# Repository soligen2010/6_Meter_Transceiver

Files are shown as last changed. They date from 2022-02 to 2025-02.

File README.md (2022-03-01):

# 6_Meter_Transceiver
A homebrew transceiver for the 6 meter Ham band
 
This project is work in progress.

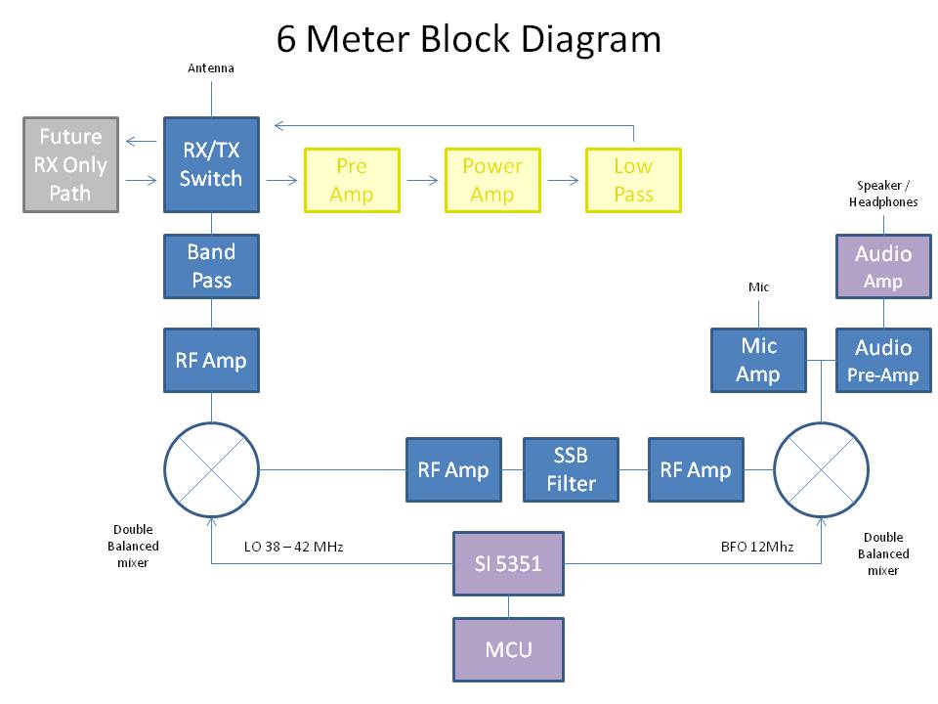
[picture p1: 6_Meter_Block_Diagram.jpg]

 
## 2022-2-27 Status
 
This is my 6 Meter homebrew transceiver, currently work in progress.  It is a single conversion super –heterodyne design.  I constructed each stage independently with SMA connectors.  This is so I can re-make sections as needed, and will allow me in the future to swap sections to experiment with alternate designs.  The VFO and BFO are controlled using a SI5351 with an Arduino micro controller.  I currently have separate SI5351 modules for VFO and BFO because I suspected issues with cross-talk.  These issues may not actually be real, so once I am happy with the performance, I will test again with just one module to see if it is OK.  The Power Amp is still on the to-do list, so output is well under 0 DBm

The Blue boards were designed by me and ordered on-line.  The other boards I etched myself.  Construction is mostly surface mount because I find it easier than drilling all the holes.  SMD components are mostly 805 and 1206 size. Transistors are SOT23.

The Band Pass filter is a 5 coil design made with air-core inductors.

3 bi-directional termination insensitive (TIA) amps are used (blue boards).  Total RX gain is about 44db.  Total TX gain is about 16db.  Each board has its own independent RX/TX switching circuitry (mosfet based) and is fed with +12.5, GND, and RX/TX logic signal from the Arduino (3V logic and up will work)
The Mixer and modulator are both Diode Ring mixers.

The 12 MHz SSB filter is a crystal ladder filter similar to the one used in the uBitx.

The Mic and audio pre-amp (also a blue board) is made on a modified TIA amp board.  I had 10 of these boards made, and the needed circuitry was largely the same, so I modified the board with a rotary tool and jumpers.

The Audio amp is a PAM8403 module and drives a headset.  I did make some modifications to the module so it runs in-spec and to eliminate the power on audio pop.

The challenges I have been having are mostly related to spurs, splatter, carrier suppression and TX audio quality.  I have been gradually tweaking these things to improve operation before I start on a power amp.  My IF is 12 MHZ, and I was using the LSB side of the crystal filter because it is sharper (VFO 62 – 66 MHz) but have recently changed over to the USB side of the filter (VFO 38 – 42 MHz).  This eliminated the spurs I was seeing near the pass band.  I still need to make some adjustments to the crystal filter as it is too broad.

I still have some splatter and audio quality seems low, but I am starting to doubt my test setup.  I see the splatter on the RTL SDR, but I don’t see it on the Tiny SA.  The spatter happens at ~160 KHz intervals.  I am hoping to find someone local with a better spectrum analyzer to help me verify if it is the rig or my SDR dongle/test setup.

The modules to the side of the picture are my rejects/experiments.  The one covered in copper shows how I eventually will shield all the modules.  I 3D printed a cover for the board, then wrapped it with copper tape, soldered to the bottom ground plane.  The one shown is a diode ring modulator.  For some unknown reason the carrier suppression is rather poor.  I had previously made a junk-box modulator that had much better carrier suppression.  I don’t know why it is better than the one I more carefully made for the radio, but until I figure it out, I am using the junk box version.  The junk box modulator uses unmatched schottkey diodes, whereas the “final” one uses a 4 diode SMD package because I wanted them matched – I thought this would be better, but maybe not.

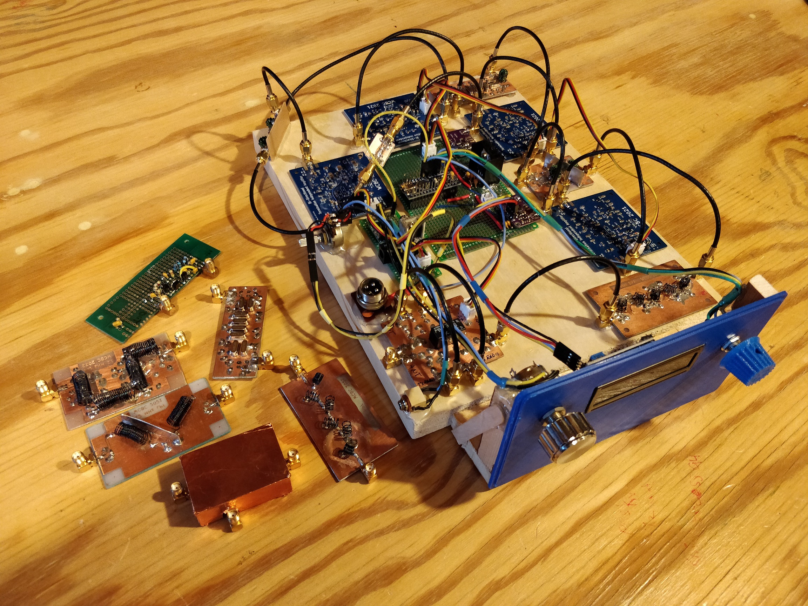
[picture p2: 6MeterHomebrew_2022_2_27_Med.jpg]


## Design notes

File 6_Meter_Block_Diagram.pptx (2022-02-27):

## 6 Meter Block Diagram

Antenna

RX/TX Switch

Band
Pass

FutureRX Only Path

Pre Amp

Power Amp

Low Pass

Speaker / Headphones

Audio Amp

Mic

Mic Amp

RF Amp

Audio Pre-Amp

RF Amp

SSB Filter

RF Amp

Double Balanced mixer

Double Balanced mixer

LO 38 – 42 MHz

SI 5351

BFO 12Mhz

MCU

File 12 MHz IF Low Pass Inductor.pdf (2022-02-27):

Air Cored Inductor Calculator (https://m0ukd.com/calculators/air-cored-inductor-calculator/)

This calculator is useful when making antenna matching units, low pass filters, crystal sets, antenna traps, resonant circuits or anywhere where an air cored single layer inductor is required.

Diameter and length of inductor are entered in millimetres along with the number of turns. Frequency can be entered to find the Q of the inductor at a specific frequency, but is not required. Inductance values are calculated to 3 decimal places and are given in nH, µH, mH and even to 5 decimal places, H! An example of a T-match inductor for 1.8MHz is already inputted, click calculate, or clear fields to enter your own values.

Input coil diameter, length & number of turns

## Calculate

## Clear Fields

Coil Diameter | 7.13 | mm
Coil length | 19 | mm
Number of turns | 19 | t

Frequency
(Not required, but used for calculating Q) | 12 | MHz

Calculated inductance, Q and wire length

Nano H | 817.972 | nH
Micro H | 0.818 | µH
Milli H | 0.001 | mH
Henry | 0.00000 | H
Inductor Q | 156 | Q
Wire Length | 0.43 | m
| 42.56 | cm
425.59 | mm Scroll to Top

This website uses cookies to improve your experience. We'll assume you're ok with this, but you can opt-out

if you wish. Accept Read More (https://m0ukd.com/)

Wire length is calculated by (diameter x π x turns). π is taken to be 3.14159265358979323846264338327950288419716939937510 which is a little over the top I know! As 39 decimal places is sufficient to estimate the circumference of any circle that fits in the observable universe with precision comparable to the radius of a hydrogen atom, the 50 decimal places I have used should be OK for your inductor. Just remember to cut a bit longer for some tails!

This website uses cookies to improve your experience. We'll assume you're ok with this, but you can opt-out

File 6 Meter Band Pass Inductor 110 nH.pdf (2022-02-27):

Air Cored Inductor Calculator (https://m0ukd.com/calculators/air-cored-inductor-calculator/)

This calculator is useful when making antenna matching units, low pass filters, crystal sets, antenna traps,

resonant circuits or anywhere where an air cored single layer inductor is required.

Diameter and length of inductor are entered in millimetres along with the number of turns. Frequency can be

entered to find the Q of the inductor at a specific frequency, but is not required. Inductance values are

calculated to 3 decimal places and are given in nH, µH, mH and even to 5 decimal places, H! An example of

a T-match inductor for 1.8MHz is already inputted, click calculate, or clear fields to enter your own values.

Input coil diameter, length & number of turns

# Calculate

# Clear Fields

Coil Diameter | 4.45 | mm
Coil length | 6.6 | mm
Number of turns | 7 | t

Frequency
(Not required, but used for calculating Q) | 1.850 | MHz

Calculated inductance, Q and wire length
Nano H | 111.413 | nH
Micro H | 0.111 | µH
Milli H | 0.000 | mH
Henry | 0.00000 | H
Inductor Q | 35 | Q
Wire Length | 0.10 | m
| 9.79 | cm
| 97.86 | mm

This website uses cookies to improve your experience. We'll assume you're ok with this, but you can opt-out

## if you wish. Accept Read More (https://m0ukd.com/)

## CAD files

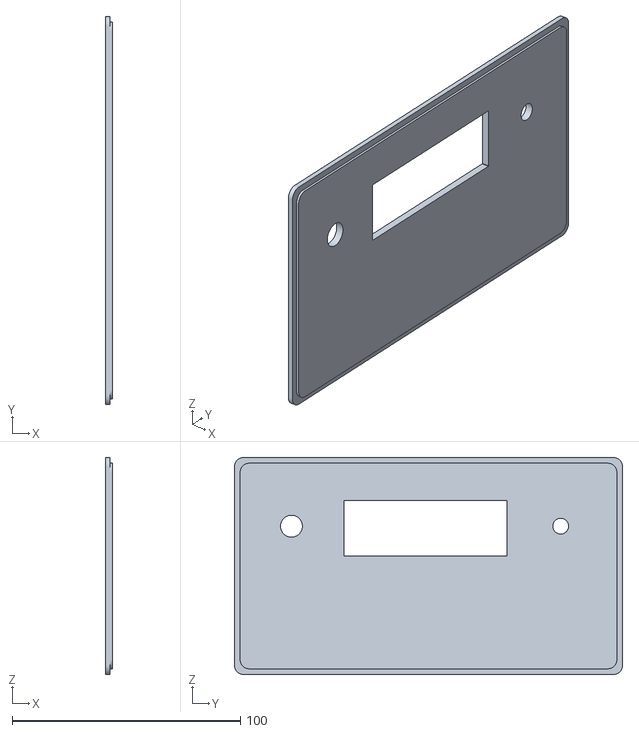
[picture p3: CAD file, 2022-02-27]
6MeterPanel.stl
3.00 x 170.1 x 95.1

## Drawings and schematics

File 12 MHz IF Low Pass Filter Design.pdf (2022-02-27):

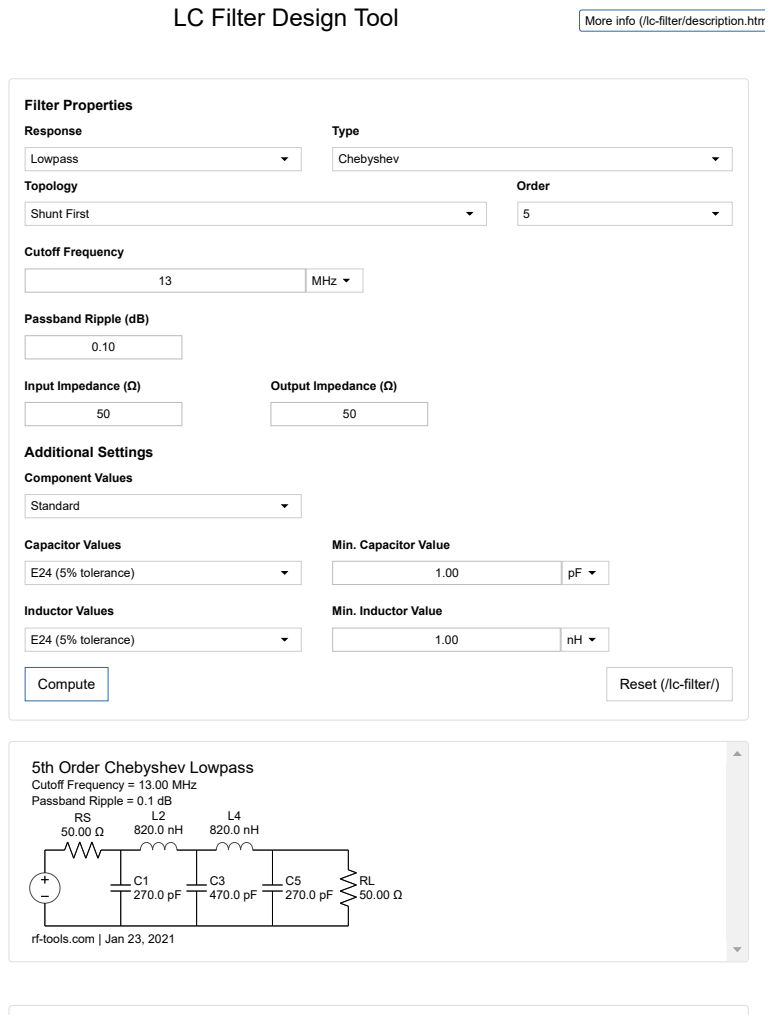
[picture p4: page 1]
LC Filter Design Tool; More info (/lc-filter/description.htm; Filter Properties; Response; Type; Topology; Order; Cutoff Frequency; Input Impedance (Ω); Output Impedance (Ω); Additional Settings; Component Values; Capacitor Values; Min. Capacitor Value; Inductor Values; Min. Inductor Value; Compute; Reset (/lc-filter/); Lowpass; Chebyshev; Shunt First; Standard; E24 (5% tolerance); MHz

Passband Ripple (dB)

5th Order Chebyshev Lowpass
Cutoff Frequency = 13.00 MHz
Passband Ripple = 0.1 dB

rf-tools.com | Jan 23, 2021

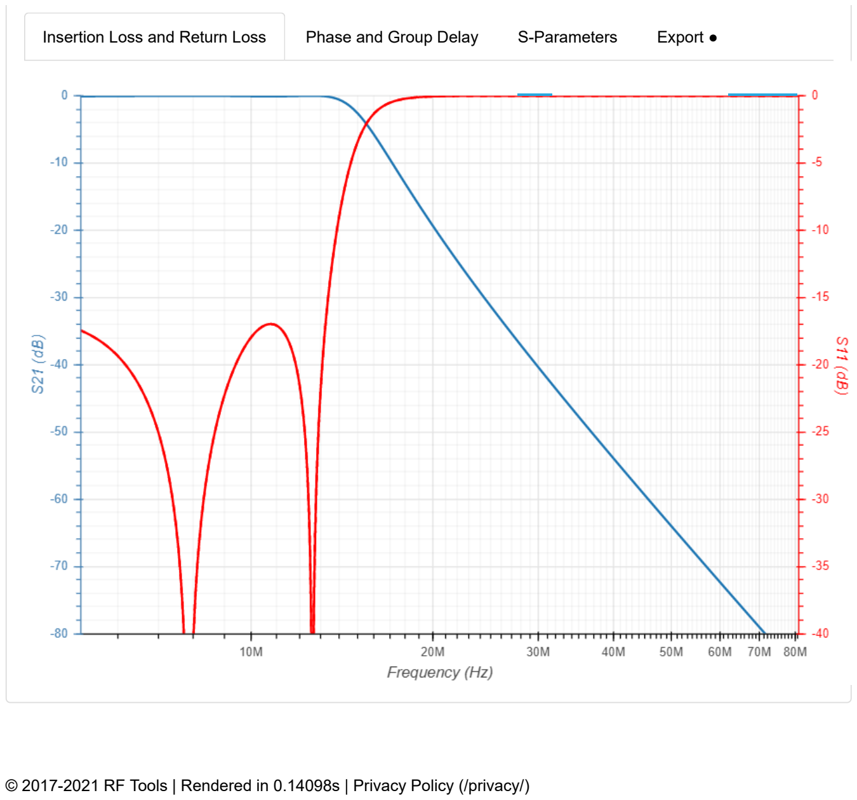
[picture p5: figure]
Insertion Loss and Return Loss; Phase and Group Delay; S-Parameters; Export ●

© 2017-2021 RF Tools | Rendered in 0.14098s | Privacy Policy (/privacy/) (https://rf-tools.com/privacy/)

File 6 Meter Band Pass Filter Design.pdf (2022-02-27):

LC Filter Design Tool | More info (/lc-filter/description.htm (https://rf-tools.com/lc-filter/description.html)

## Filter Properties

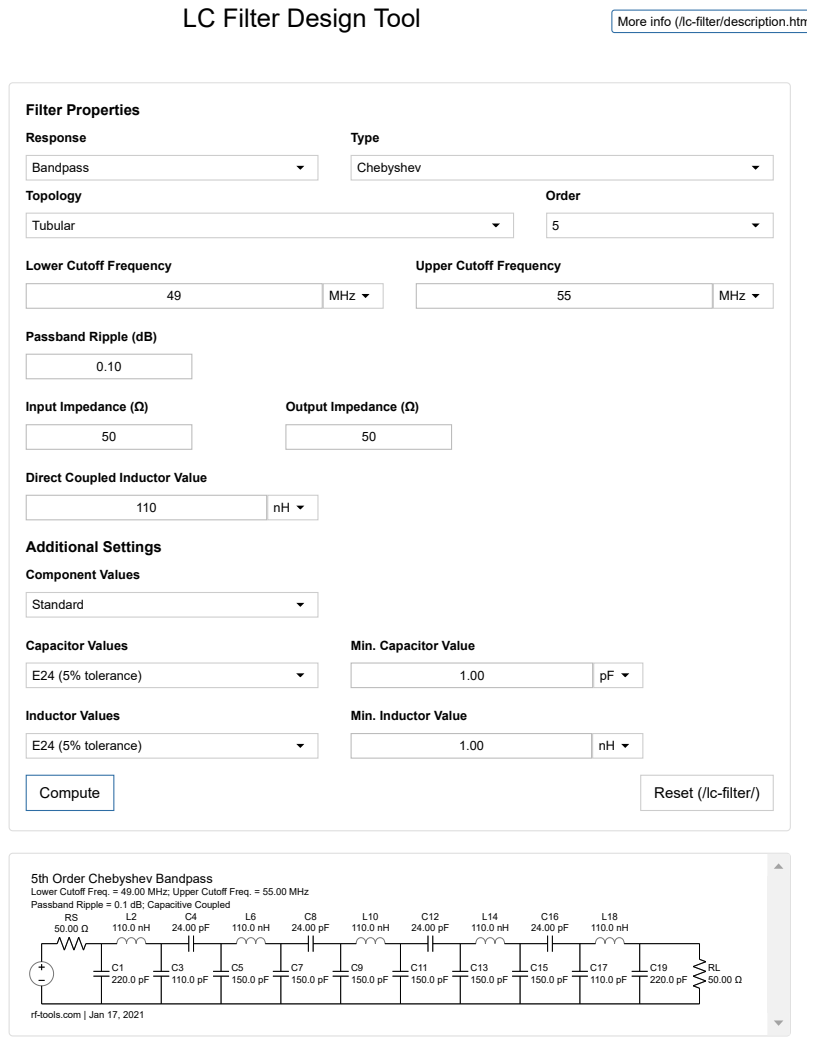
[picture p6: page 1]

Direct Coupled Inductor Value

5th Order Chebyshev Bandpass
Lower Cutoff Freq. = 49.00 MHz; Upper Cutoff Freq. = 55.00 MHz
Passband Ripple = 0.1 dB; Capacitive Coupled

rf-tools.com | Jan 17, 2021

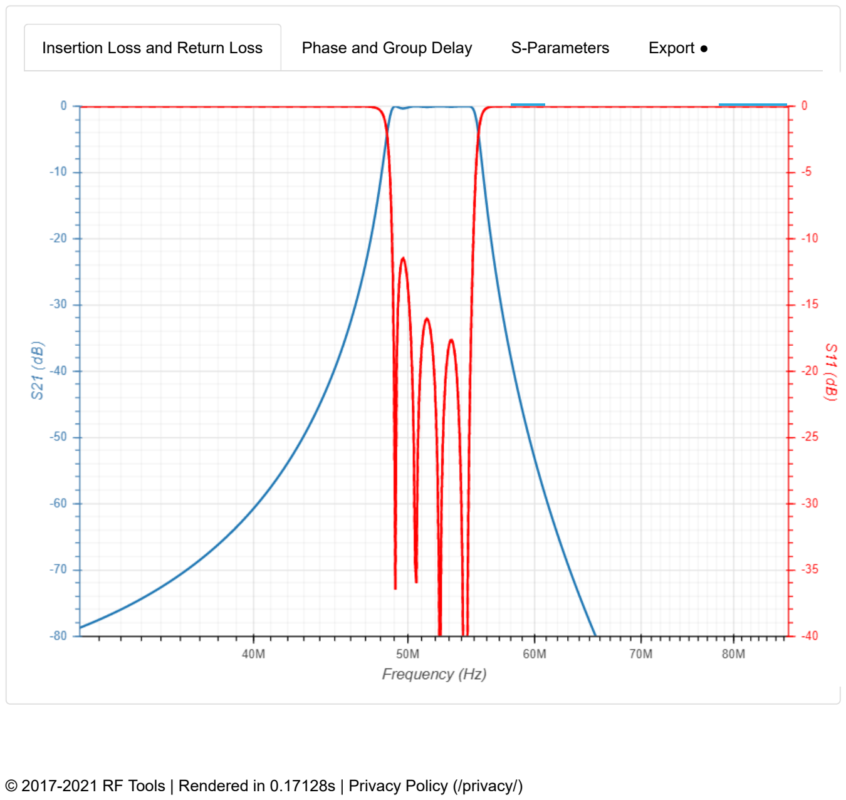
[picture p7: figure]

© 2017-2021 RF Tools | Rendered in 0.17128s | Privacy Policy (/privacy/) (https://rf-tools.com/privacy/)
Insertion Loss and Return Loss | Phase and Group Delay | S-Parameters | Export ●

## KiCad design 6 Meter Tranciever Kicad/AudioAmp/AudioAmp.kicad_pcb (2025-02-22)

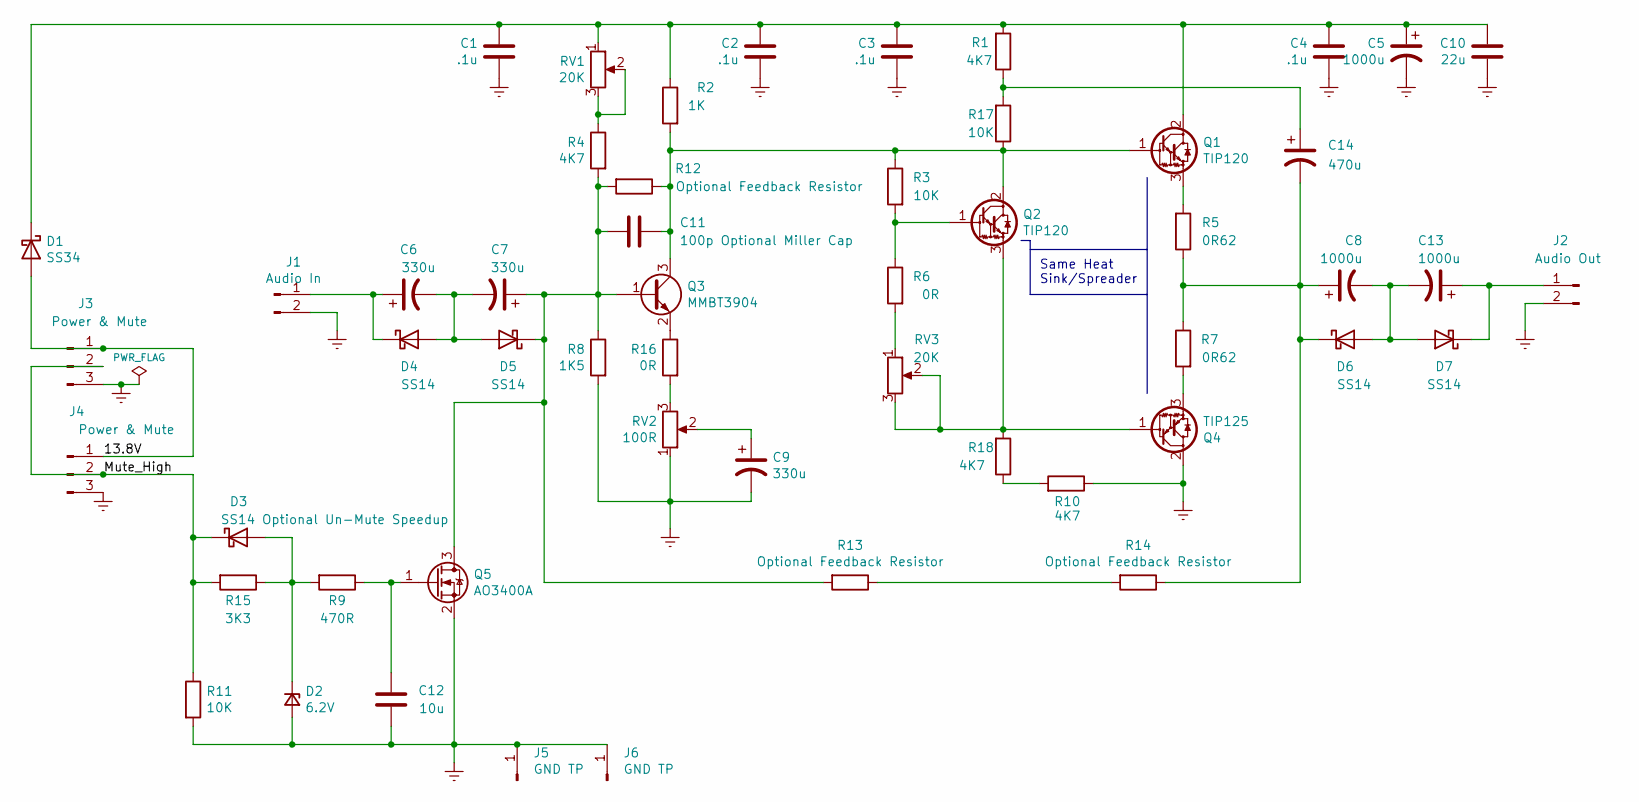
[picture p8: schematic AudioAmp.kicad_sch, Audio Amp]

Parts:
C1, C2, C3, C4: .1u; SMD_Combo_1206_0805
C5: 1000u; CP_Radial_D18.0mm_P7.50mm
C6, C7, C9: 330u; CP_Radial_D13.0mm_P5.00mm
C8, C13: 1000u; CP_Radial_D13.0mm_P5.00mm
C10: 22u; SMD_Combo_1206_0805
C11: 100p Optional Miller Cap; SMD_Combo_1206_0805
C12: 10u; SMD_Combo_1206_0805
C14: 470u; CP_Radial_D13.0mm_P5.00mm
D1: SS34; D_SMA_Handsoldering
D2: 6.2V; D_MiniMELF_Handsoldering
D3: SS14 Optional Un-Mute Speedup; D_SMA_Handsoldering
D4, D5, D6, D7: SS14; D_SMA_Handsoldering
J1: Audio In; Molex_KK-254_AE-6410-02A_1x02_P2.54mm_Vertical
J2: Audio Out; Molex_KK-254_AE-6410-02A_1x02_P2.54mm_Vertical
J3, J4: Power & Mute; FanPinHeader_1x03_P2.54mm_Vertical
J5, J6: GND TP; PinHeader_1x01_P2.54mm_Vertical
Q1, Q2: TIP120; TO-220-3_Vertical
Q3: MMBT3904; SOT-23_Handsoldering
Q4: TIP125; TO-220-3_Vertical
Q5: AO3400A; SOT-23_Handsoldering
R1, R4, R10, R18: 4K7; SMD_Combo_1206_0805
R2: 1K; SMD_Combo_1206_0805
R3, R11, R17: 10K; SMD_Combo_1206_0805
R5, R7: 0R62; R_Axial_DIN0309_L9.0mm_D3.2mm_P12.70mm_Horizontal
R6, R16: 0R; SMD_Combo_1206_0805
R8: 1K5; SMD_Combo_1206_0805
R9: 470R; SMD_Combo_1206_0805
R12, R13, R14: Optional Feedback Resistor; SMD_Combo_1206_0805
R15: 3K3; SMD_Combo_1206_0805
RV1, RV3: 20K; Potentiometer_Piher_PT-6-V_Vertical
RV2: 100R; Potentiometer_Piher_PT-6-V_Vertical

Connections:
/13.8V: D1.2 (A), J3.1, J4.1
/Mute_High: D3.1 (K), J3.2, J4.2, R11.1, R15.2
GNDREF: C1.2, C2.2, C3.2, C4.2, C5.2, C9.2, C10.2, C12.2, D2.2 (A), J1.2, J2.2, J3.3, J4.3, J5.1, J6.1, Q4.2 (C), Q5.2 (S), R8.2, R10.1, R11.2, RV2.1
unnamed: C1.1, C2.1, C3.1, C4.1, C5.1, C10.1, D1.1 (K), Q1.2 (C), R1.2, R2.1, RV1.1
unnamed: C6.1, D4.1 (K), J1.1
unnamed: C6.2, C7.2, D4.2 (A), D5.2 (A)
unnamed: C8.1, C14.2, D6.1 (K), R5.1, R7.1, R14.1
unnamed: C9.1, RV2.2
unnamed: C11.1, Q1.1 (B), Q2.2 (C), Q3.3 (C), R2.2, R3.1, R12.1, R17.1
unnamed: C7.1, C11.2, D5.1 (K), Q3.1 (B), Q5.3 (D), R4.2, R8.1, R12.2, R13.2
unnamed: C12.1, Q5.1 (G), R9.1
unnamed: C13.1, D7.1 (K), J2.1
unnamed: C8.2, C13.2, D6.2 (A), D7.2 (A)
unnamed: C14.1, R1.1, R17.2
unnamed: D2.1 (K), D3.2 (A), R9.2, R15.1
unnamed: Q1.3 (E), R5.2
unnamed: Q2.1 (B), R3.2, R6.1
unnamed: Q2.3 (E), Q4.1 (B), R18.2, RV3.2, RV3.3
unnamed: Q3.2 (E), R16.1
unnamed: Q4.3 (E), R7.2
unnamed: R4.1, RV1.2, RV1.3
unnamed: R6.2, RV3.1
unnamed: R10.2, R18.1
unnamed: R13.1, R14.2
unnamed: R16.2, RV2.3

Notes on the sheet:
Same Heat Sink/Spreader

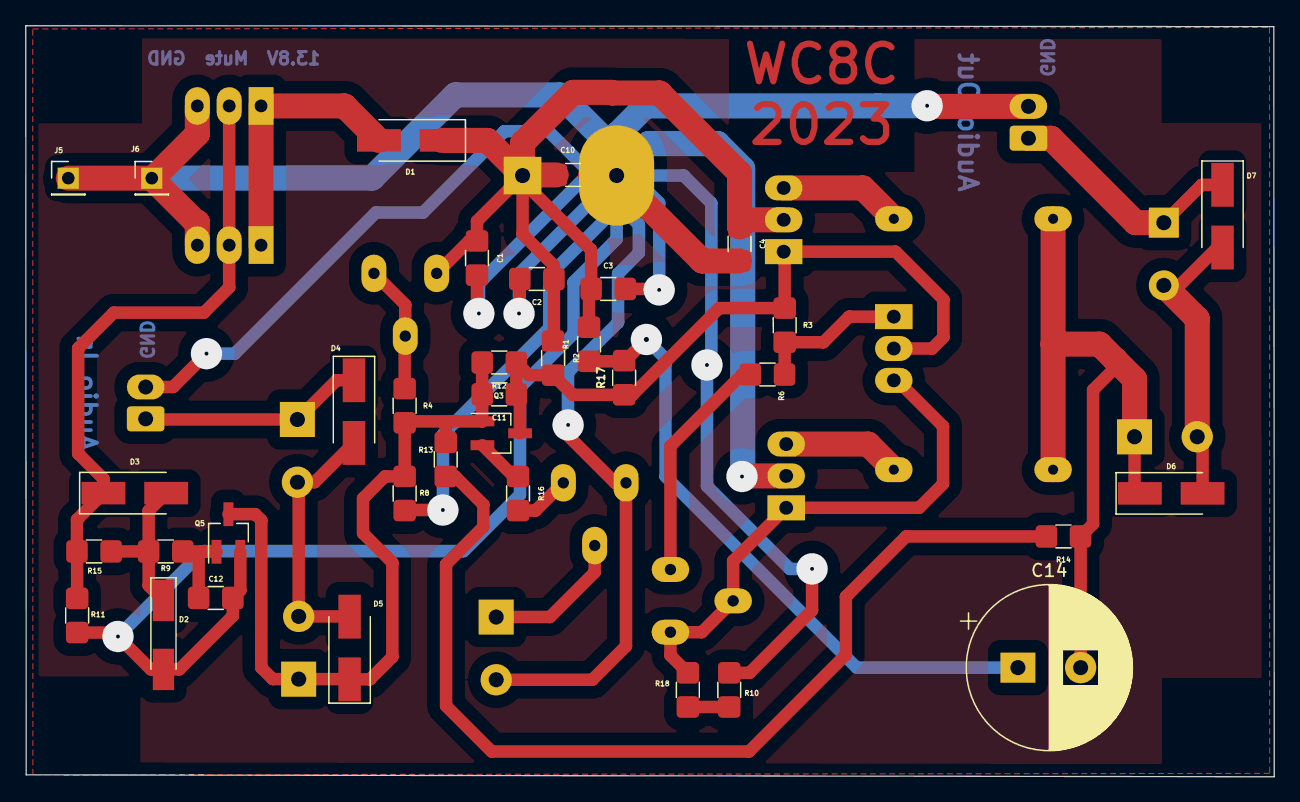
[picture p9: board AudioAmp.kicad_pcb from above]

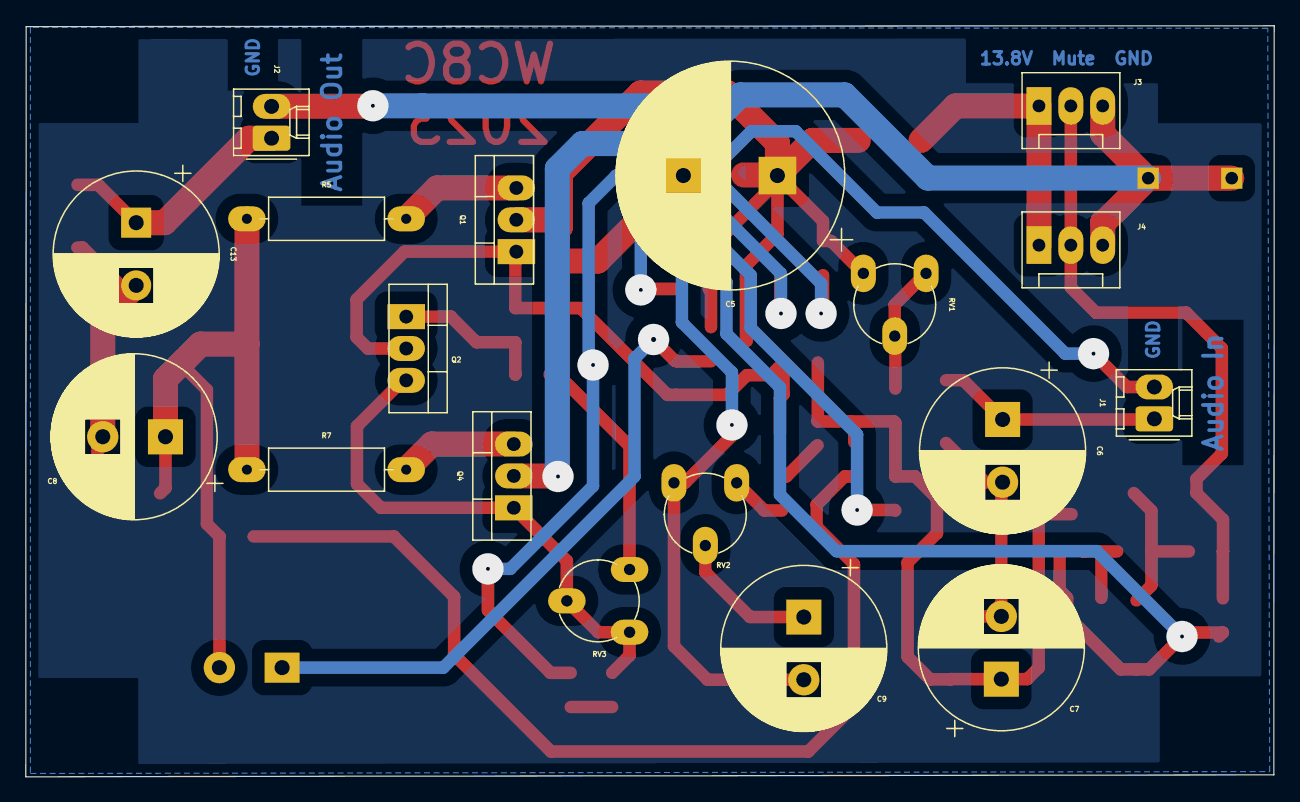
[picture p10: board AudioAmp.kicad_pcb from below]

Board: 2 copper layers, 99.5 x 59.9 mm, 53 parts (18 on the bottom side), 25 nets.

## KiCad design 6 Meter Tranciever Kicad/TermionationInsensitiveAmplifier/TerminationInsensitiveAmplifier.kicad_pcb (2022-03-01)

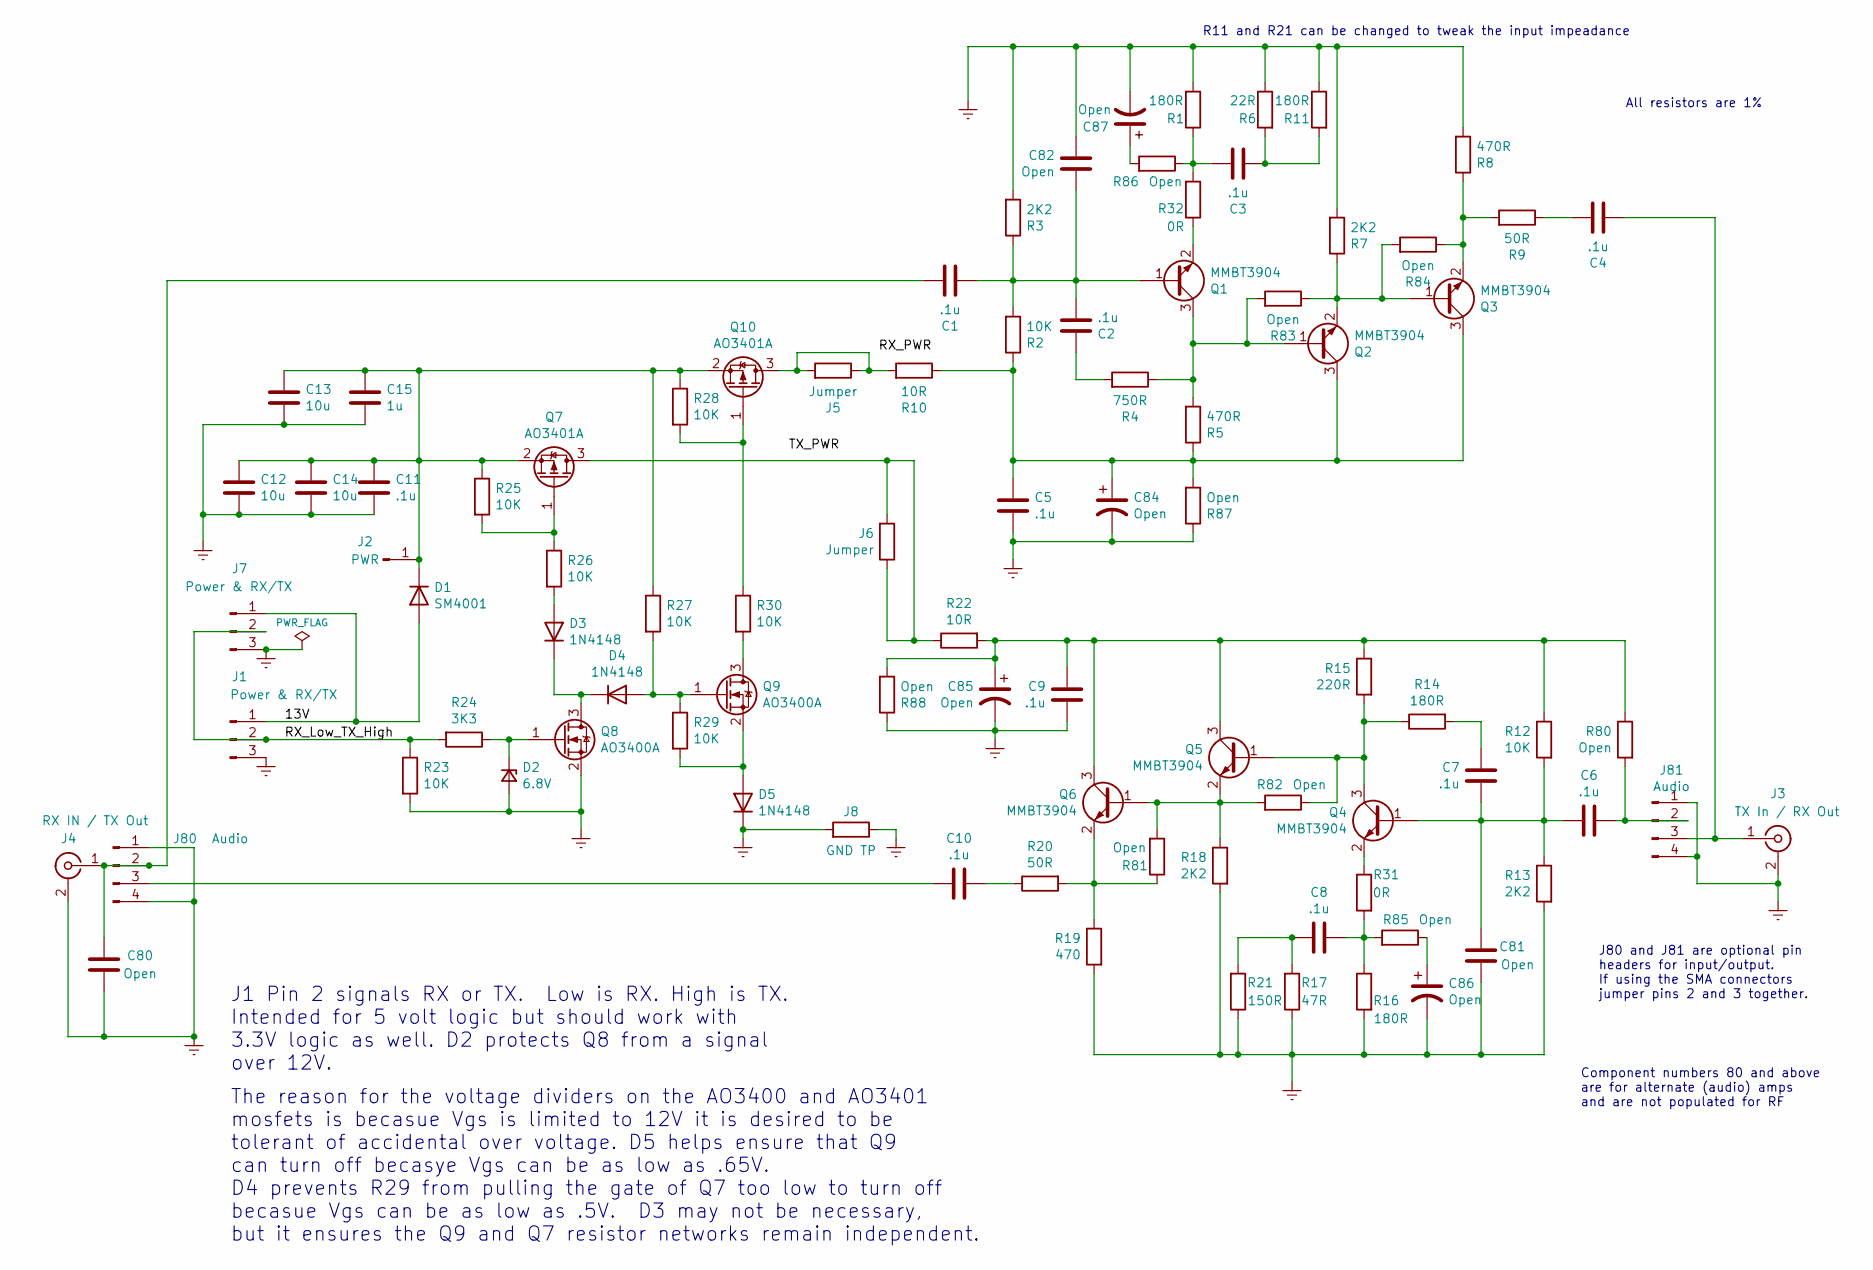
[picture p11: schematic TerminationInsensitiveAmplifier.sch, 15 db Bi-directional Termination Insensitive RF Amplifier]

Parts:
C1, C4, C6, C10: .1u; Cap_0805_1206_6032
C2, C3, C5, C7, C8, C9, C11: .1u; SMD_Combo_1206_0805
C12, C13, C14: 10u; SMD_Combo_1206_0805
C15: 1u; SMD_Combo_1206_0805
C80, C81, C82: Open; SMD_Combo_1206_0805
C84, C85, C86, C87: Open; Cap_0805_1206_6032
D1: SM4001; D_SMA_Handsoldering
D2: 6.8V; D_MiniMELF_Handsoldering
D3, D4, D5: 1N4148; D_SOD-323_HandSoldering
J1, J7: Power & RX/TX; FanPinHeader_1x03_P2.54mm_Vertical
J2: PWR; PinHeader_1x01_P2.54mm_Vertical
J3: TX In / RX Out; SMA_Molex_73251-2120_EdgeMount_Horizontal
J4: RX IN / TX Out; SMA_Molex_73251-2120_EdgeMount_Horizontal
J5, J6: Jumper; R_Axial_DIN0207_L6.3mm_D2.5mm_P7.62mm_Horizontal
J8: GND TP; R_Axial_DIN0207_L6.3mm_D2.5mm_P7.62mm_Horizontal
J80, J81: Audio; PinSocket_1x04_P2.54mm_Vertical
Q1, Q2, Q3, Q4, Q5, Q6: MMBT3904; SOT-23_Handsoldering
Q7, Q10: AO3401A; SOT-23_Handsoldering
Q8, Q9: AO3400A; SOT-23_Handsoldering
R1, R11, R14, R16: 180R; SMD_Combo_1206_0805
R2, R12, R23, R25, R26, R27, R28, R29, R30: 10K; SMD_Combo_1206_0805
R3, R7, R13, R18: 2K2; SMD_Combo_1206_0805
R4: 750R; SMD_Combo_1206_0805
R5, R8: 470R; SMD_Combo_1206_0805
R6: 22R; SMD_Combo_1206_0805
R9, R20: 50R; SMD_Combo_1206_0805
R10, R22: 10R; SMD_Combo_1206_0805
R15: 220R; SMD_Combo_1206_0805
R17: 47R; SMD_Combo_1206_0805
R19: 470; SMD_Combo_1206_0805
R21: 150R; SMD_Combo_1206_0805
R24: 3K3; SMD_Combo_1206_0805
R31, R32: 0R; SMD_Combo_1206_0805
R80, R81, R82, R83, R84, R85, R86, R87, R88: Open; SMD_Combo_1206_0805

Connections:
/13V: D1.2 (A), J1.1, J7.1
/RX_Low_TX_High: J1.2, J7.2, R23.1, R24.2
GNDREF: C5.2, C9.2, C11.2, C12.2, C13.2, C14.2, C15.2, C80.1, C81.2, C82.1, C84.2, C85.2, C86.2, C87.2, D2.2 (A), D5.1 (K), J1.3, J3.2 (Ext), J4.2 (Ext), J7.3, J8.1, J8.2, J80.1, J80.4, J81.1, J81.4, Q8.2 (S), R1.2, R3.2, R6.1, R7.2, R8.2, R11.1, R13.2, R16.2, R17.1, R18.2, R19.2, R21.1, R23.2, R87.1, R88.1; also elsewhere on the board
unnamed: C1.1, C2.2, C82.2, Q1.1 (B), R2.2, R3.1
unnamed: C1.2, C80.2, J4.1 (In), J80.2
unnamed: C2.1, R4.2
unnamed: C3.1, R6.2, R11.2
unnamed: C3.2, R1.1, R32.2, R86.1
unnamed: C4.1, J3.1 (In), J81.3
unnamed: C4.2, R9.1
unnamed 10: C5.1, C84.1, Q2.3 (C), Q3.3 (C), R2.1, R5.1, R10.1, R87.2; also elsewhere on the board
unnamed: C6.1, C7.2, C81.1, Q4.1 (B), R12.2, R13.1
unnamed: C6.2, J81.2, R80.2
unnamed: C7.1, R14.2
unnamed: C8.1, R17.2, R21.2
unnamed: C8.2, R16.1, R31.2, R85.2
unnamed: C10.1, J80.3
unnamed: C10.2, R20.1
unnamed: C11.1, C12.1, C13.1, C14.1, C15.1, D1.1 (K), J2.1, Q7.2 (S), Q10.2 (S), R25.1, R27.1, R28.1
unnamed 19: C9.1, C85.1, Q5.3 (C), Q6.3 (C), R12.1, R15.1, R22.2, R80.1, R88.2; also elsewhere on the board
unnamed 20: C86.1, R85.1; also elsewhere on the board
unnamed 21: C87.1, R86.2; also elsewhere on the board
unnamed: D2.1 (K), Q8.1 (G), R24.1
unnamed: D3.1 (K), D4.1 (K), Q8.3 (D)
unnamed: D3.2 (A), R26.2
unnamed: D4.2 (A), Q9.1 (G), R27.2, R29.1
unnamed: D5.2 (A), Q9.2 (S), R29.2
unnamed: J5.1, J5.2, Q10.3 (D), R10.2
unnamed: J6.1, J6.2, Q7.3 (D), R22.1
unnamed: Q1.2 (E), R32.1
unnamed: Q1.3 (C), Q2.1 (B), R4.1, R5.2, R83.2
unnamed: Q2.2 (E), Q3.1 (B), R7.1, R83.1, R84.2
unnamed: Q3.2 (E), R8.1, R9.2, R84.1
unnamed: Q4.2 (E), R31.1
unnamed: Q4.3 (C), Q5.1 (B), R14.1, R15.2, R82.1
unnamed: Q5.2 (E), Q6.1 (B), R18.1, R81.2, R82.2
unnamed: Q6.2 (E), R19.1, R20.2, R81.1
unnamed: Q7.1 (G), R25.2, R26.1
unnamed: Q9.3 (D), R30.2
unnamed: Q10.1 (G), R28.2, R30.1

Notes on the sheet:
The reason for the voltage dividers on the AO3400 and AO3401 mosfets is becasue Vgs is limited to 12V it is desired to be tolerant of accidental over voltage. D5 helps ensure that Q9 can turn off becasye Vgs can be as low as .65V. D4 prevents R29 from pulling the gate of Q7 too low to turn off beca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
J1 Pin 2 signals RX or TX. Low is RX. High is TX. Intended for 5 volt logic but should work with 3.3V logic as well. D2 protects Q8 from a signal over 12V.
R11 and R21 can be changed to tweak the input impeadance
All resistors are 1%
J80 and J81 are optional pin headers for input/output. If using the SMA connectors jumper pins 2 and 3 together.
Component numbers 80 and above are for alternate (audio) amps and are not populated for RF

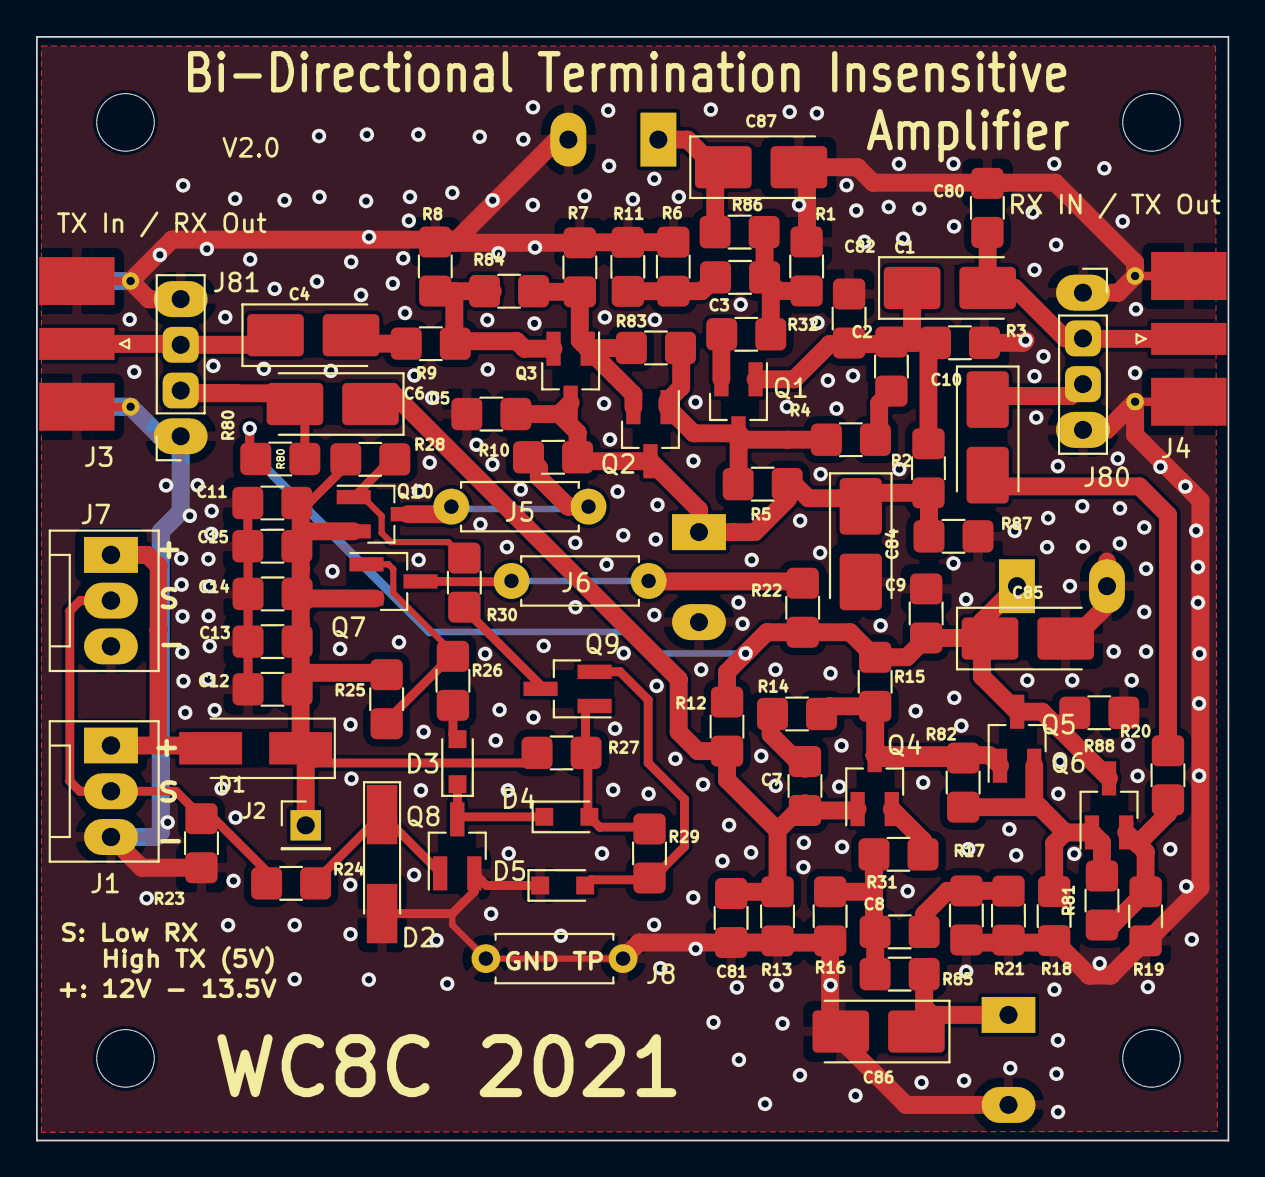
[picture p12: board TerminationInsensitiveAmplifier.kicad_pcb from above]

Board: 2 copper layers, 66.2 x 61.3 mm, 96 parts (0 on the bottom side), 40 nets.

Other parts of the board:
 : 5mm_Pads
 #2,  #3,  #4: 5mm_Pads
 #5,  #6,  #7,  #8: MountingHole_3.2mm_M3

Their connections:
GNDREF: .2, #2.2, #3.2, #4.2; also elsewhere on the board
unnamed 10: .1; also elsewhere on the board
unnamed 19: #2.1; also elsewhere on the board
unnamed 20: #4.1; also elsewhere on the board
unnamed 21: #3.1; also elsewhere on the board

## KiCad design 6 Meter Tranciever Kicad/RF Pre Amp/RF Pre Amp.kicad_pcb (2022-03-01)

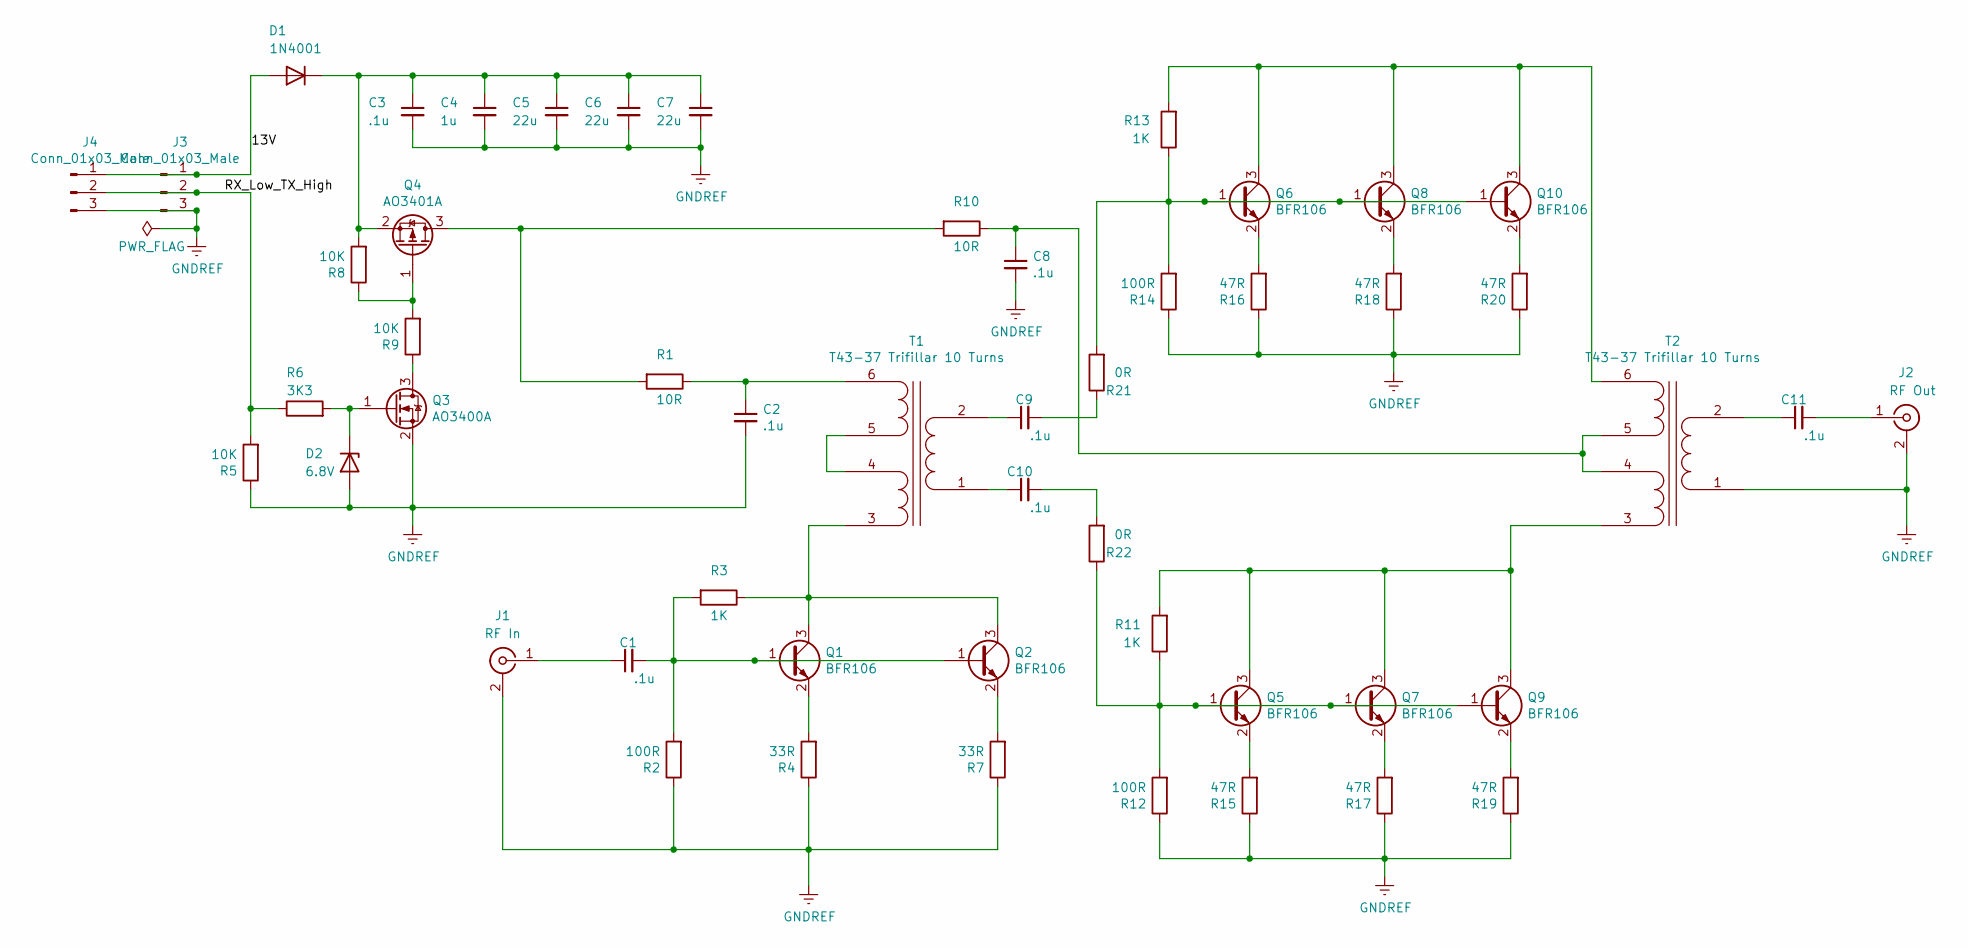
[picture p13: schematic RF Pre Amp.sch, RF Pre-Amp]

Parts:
C1, C2, C3, C8, C9, C10, C11: .1u; SMD_Combo_1206_0805
C4: 1u; SMD_Combo_1206_0805
C5, C6, C7: 22u; SMD_Combo_1206_0805
D1: 1N4001; D_2114_3652Metric_Pad1.85x3.75mm_HandSolder
D2: 6.8V; D_MiniMELF_Handsoldering
J1: RF In; SMA_Molex_73251-2120_EdgeMount_Horizontal
J2: RF Out; SMA_Molex_73251-2120_EdgeMount_Horizontal
J3, J4: Conn_01x03_Male; FanPinHeader_1x03_P2.54mm_Vertical
Q1, Q2, Q5, Q6, Q7, Q8, Q9, Q10: BFR106; SOT-323_SC-70_Handsoldering
Q3: AO3400A; SOT-323_SC-70_Handsoldering
Q4: AO3401A; SOT-323_SC-70_Handsoldering
R1, R10: 10R; SMD_Combo_1206_0805
R2, R12, R14: 100R; SMD_Combo_1206_0805
R3, R11, R13: 1K; SMD_Combo_1206_0805
R4, R7: 33R; SMD_Combo_1206_0805
R5, R8, R9: 10K; SMD_Combo_1206_0805
R6: 3K3; SMD_Combo_1206_0805
R15, R16, R17, R18, R19, R20: 47R; SMD_Combo_1206_0805
R21, R22: 0R; SMD_Combo_1206_0805
T1, T2: T43-37 Trifillar 10 Turns; T37_Trifillar

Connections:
/13V: D1.2 (A), J3.1, J4.1
/RX_Low_TX_High: J3.2, J4.2, R5.2, R6.1
GNDREF: C2.2, C3.2, C4.2, C5.2, C6.2, C7.2, C8.2, D2.2 (A), J1.2 (Ext), J2.2 (Ext), J3.3, J4.3, Q3.2 (S), R2.1, R4.1, R5.1, R7.1, R12.1, R14.1, R15.1, R16.1, R17.1, R18.1, R19.1, R20.1, T2.1 (AA)
unnamed: C1.1, J1.1 (In)
unnamed: C1.2, Q1.1 (B), Q2.1 (B), R2.2, R3.2
unnamed: C2.1, R1.1, T1.6 (SD)
unnamed: C3.1, C4.1, C5.1, C6.1, C7.1, D1.1 (K), Q4.2 (S), R8.2
unnamed: C8.1, R10.1, T2.4 (SB), T2.5 (SC)
unnamed: C9.1, T1.2 (AB)
unnamed: C9.2, R21.1
unnamed: C10.1, T1.1 (AA)
unnamed: C10.2, R22.2
unnamed: C11.1, T2.2 (AB)
unnamed: C11.2, J2.1 (In)
unnamed: D2.1 (K), Q3.1 (G), R6.2
unnamed: Q1.2 (E), R4.2
unnamed: Q1.3 (C), Q2.3 (C), R3.1, T1.3 (SA)
unnamed: Q2.2 (E), R7.2
unnamed: Q3.3 (D), R9.1
unnamed: Q4.1 (G), R8.1, R9.2
unnamed: Q4.3 (D), R1.2, R10.2
unnamed: Q5.1 (B), Q7.1 (B), Q9.1 (B), R11.1, R12.2, R22.1
unnamed: Q5.2 (E), R15.2
unnamed: Q5.3 (C), Q7.3 (C), Q9.3 (C), R11.2, T2.3 (SA)
unnamed: Q6.2 (E), R16.2
unnamed: Q7.2 (E), R17.2
unnamed: Q8.2 (E), R18.2
unnamed: Q9.2 (E), R19.2
unnamed: Q6.1 (B), Q8.1 (B), Q10.1 (B), R13.1, R14.2, R21.2
unnamed: Q10.2 (E), R20.2
unnamed: Q6.3 (C), Q8.3 (C), Q10.3 (C), R13.2, T2.6 (SD)
unnamed: T1.4 (SB), T1.5 (SC)

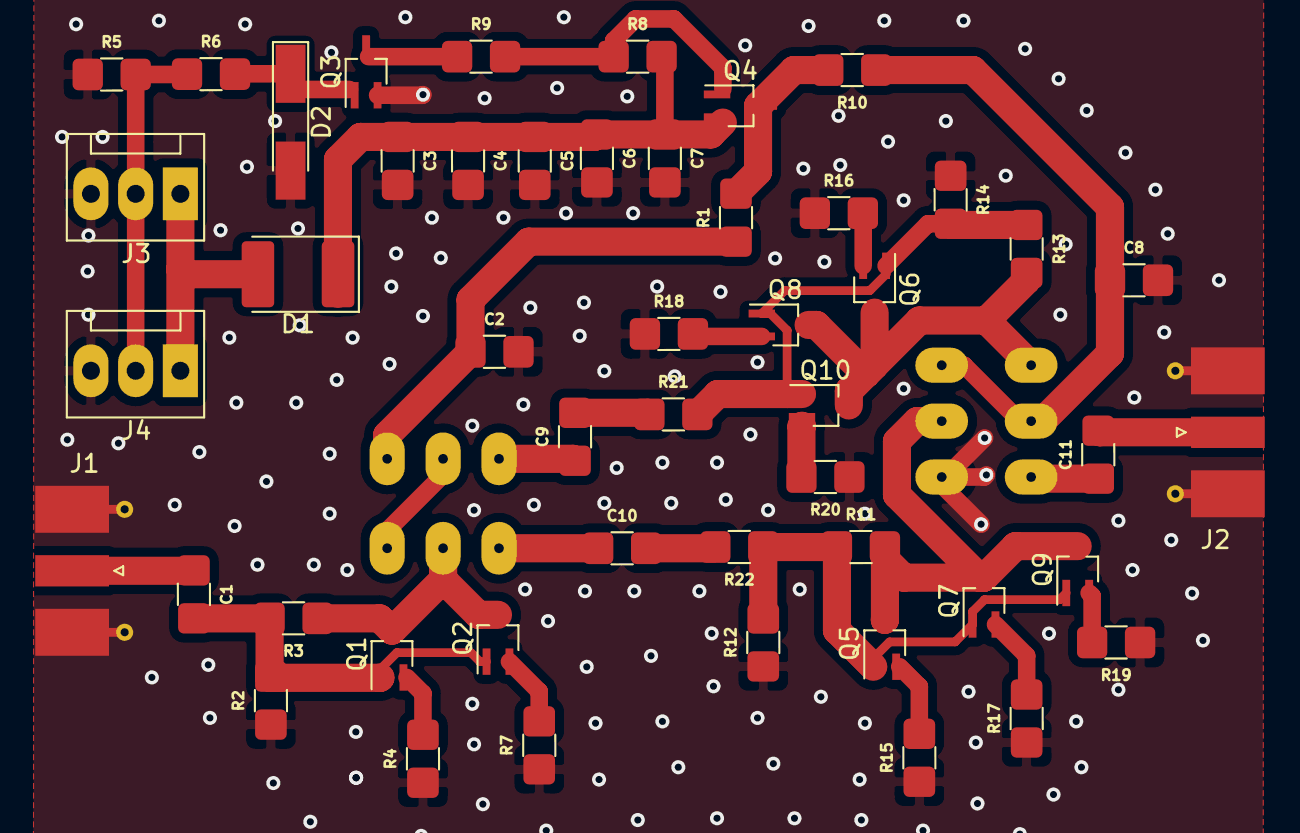
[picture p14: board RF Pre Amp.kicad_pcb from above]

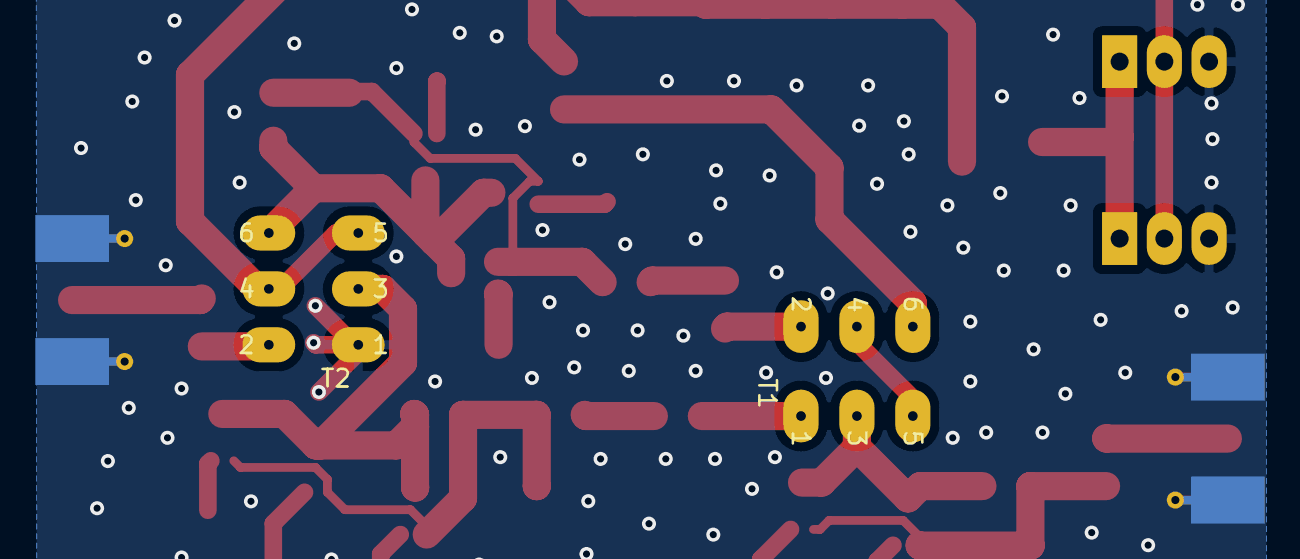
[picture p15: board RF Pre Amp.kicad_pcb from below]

Board: 2 copper layers, 51 parts (2 on the bottom side), 32 nets.

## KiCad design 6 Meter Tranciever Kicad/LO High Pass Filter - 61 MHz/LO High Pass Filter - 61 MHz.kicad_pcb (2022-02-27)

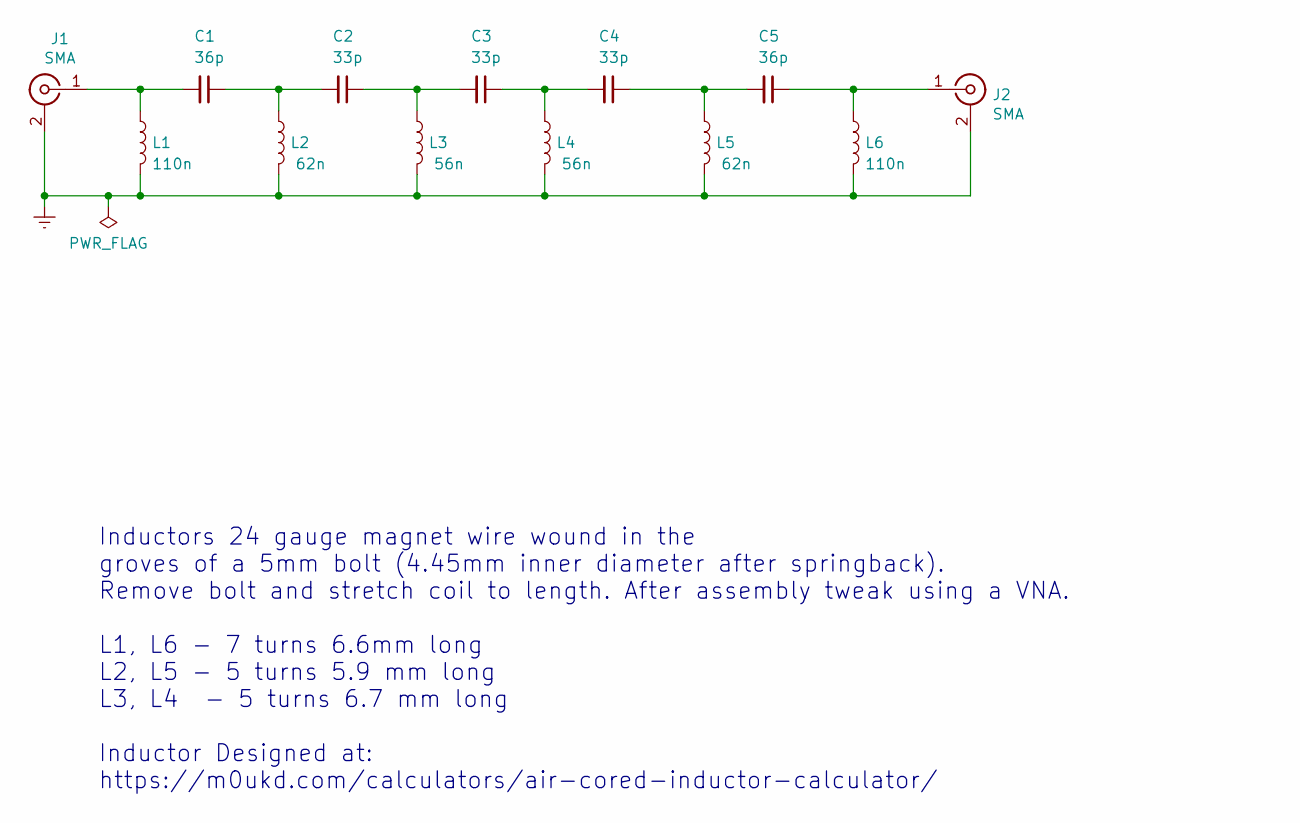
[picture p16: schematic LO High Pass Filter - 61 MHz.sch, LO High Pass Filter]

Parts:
C1, C5: 36p; SMD_Combo_1206_0805
C2, C3, C4: 33p; SMD_Combo_1206_0805
J1, J2: SMA; SMA_Molex_73251-2120_EdgeMount_Horizontal
L1, L6: 110n; Air_Inductor_6.75mm
L2, L5: 62n; Air_Inductor_6.75mm
L3, L4: 56n; Air_Inductor_6mm

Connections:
GNDREF: J1.2 (Ext), J2.2 (Ext), L1.2, L2.2, L3.2, L4.2, L5.2, L6.2
unnamed: C1.1, C2.2, L2.1
unnamed: C1.2, J1.1 (In), L1.1
unnamed: C2.1, C3.2, L3.1
unnamed: C3.1, C4.2, L4.1
unnamed: C4.1, C5.2, L5.1
unnamed: C5.1, J2.1 (In), L6.1

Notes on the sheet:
Inductors 24 gauge magnet wire wound in the groves of a 5mm bolt (4.45mm inner diameter after springback). Remove bolt and stretch coil to length. After assembly tweak using a VNA. L1, L6 - 7 turns 6.6mm long L2, L5 - 5 turns 5.9 mm long L3, L4 - 5 turns 6.7 mm long Inductor Designed at: https://m0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

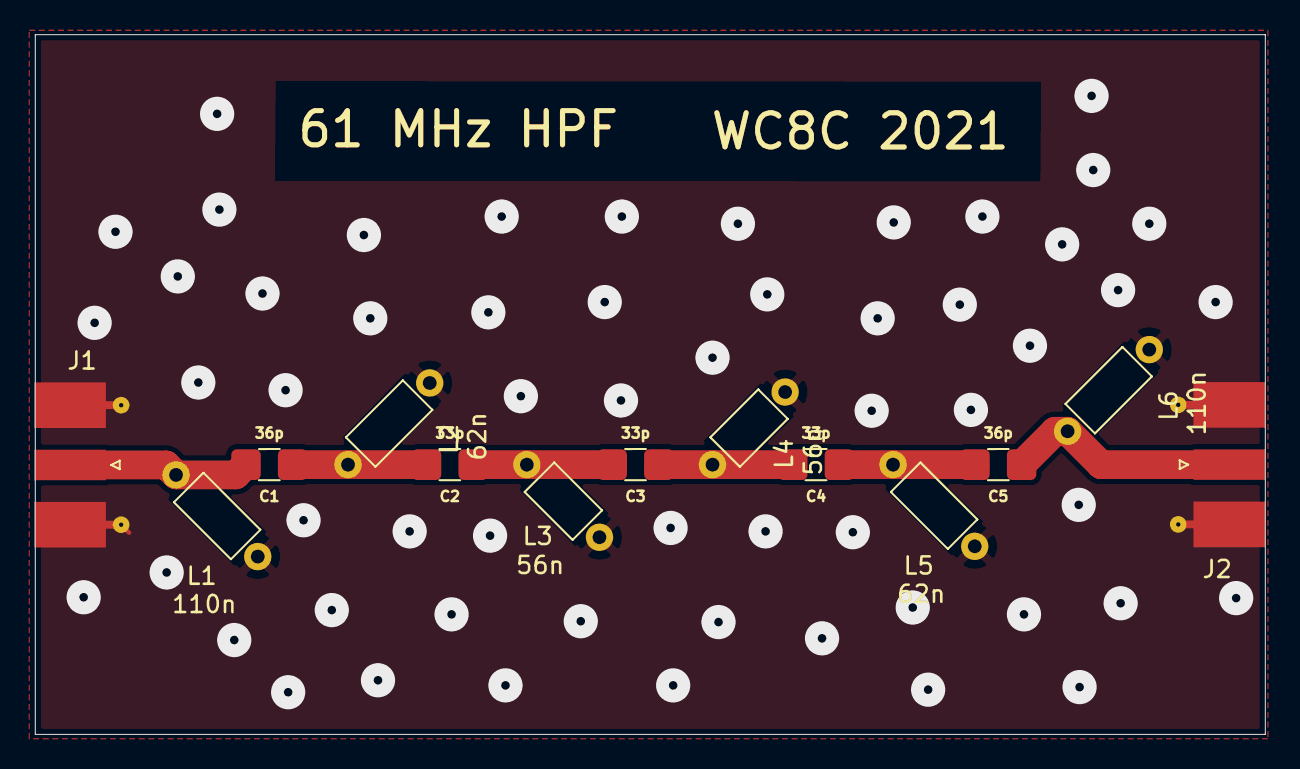
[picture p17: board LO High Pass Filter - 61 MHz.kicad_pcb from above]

Board: 2 copper layers, 71.9 x 40.9 mm, 13 parts (0 on the bottom side), 7 nets.

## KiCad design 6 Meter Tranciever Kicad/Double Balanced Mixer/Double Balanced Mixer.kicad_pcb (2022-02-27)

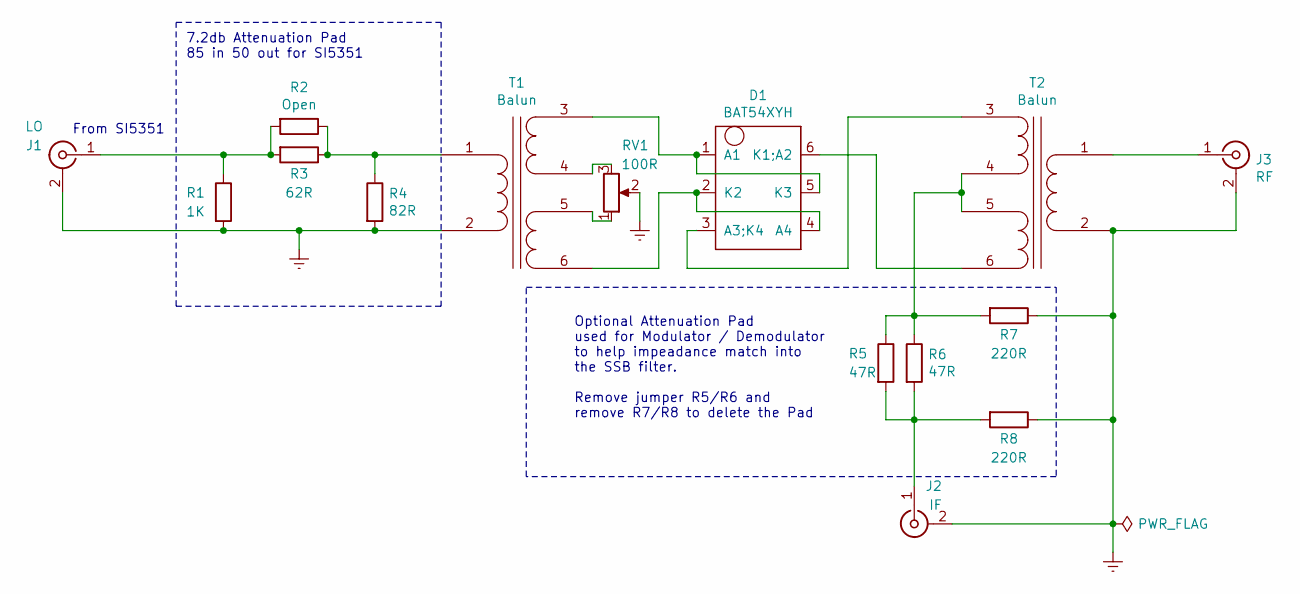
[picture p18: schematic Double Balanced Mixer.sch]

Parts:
D1: BAT54XYH; SOT-363_SC-70-6_Handsoldering
J1: LO; SMA_Molex_73251-2120_EdgeMount_Horizontal
J2: IF; SMA_Molex_73251-2120_EdgeMount_Horizontal
J3: RF; SMA_Molex_73251-2120_EdgeMount_Horizontal
R1: 1K; SMD_Combo_1206_0805
R2: Open; SMD_Combo_1206_0805
R3: 62R; SMD_Combo_1206_0805
R4: 82R; SMD_Combo_1206_0805
R5, R6: 47R; SMD_Combo_1206_0805
R7, R8: 220R; SMD_Combo_1206_0805
RV1: 100R; Potentiometer_Piher_PT-6-V_Vertical
T1, T2: Balun; T37_Trifillar

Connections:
GNDREF: J1.2 (Ext), J2.2 (Ext), J3.2 (Ext), R1.2, R4.2, R7.1, R8.1, RV1.2, T1.2 (AB), T2.2 (AB)
unnamed: D1.1 (A1), D1.5 (K3), T1.3 (SA)
unnamed: D1.2 (K2), D1.4 (A4), T1.6 (SD)
unnamed: D1.3 (A3;K4), T2.3 (SA)
unnamed: D1.6 (K1;A2), T2.6 (SD)
unnamed: J1.1 (In), R1.1, R2.2, R3.2
unnamed: J2.1 (In), R5.2, R6.2, R8.2
unnamed: J3.1 (In), T2.1 (AA)
unnamed: R2.1, R3.1, R4.1, T1.1 (AA)
unnamed: R5.1, R6.1, R7.2, T2.4 (SB), T2.5 (SC)
unnamed: RV1.1, T1.5 (SC)
unnamed: RV1.3, T1.4 (SB)

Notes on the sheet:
7.2db Attenuation Pad 85 in 50 out for SI5351
From SI5351
Optional Attenuation Pad used for Modulator / Demodulator to help impeadance match into the SSB filter. Remove jumper R5/R6 and remove R7/R8 to delete the Pad

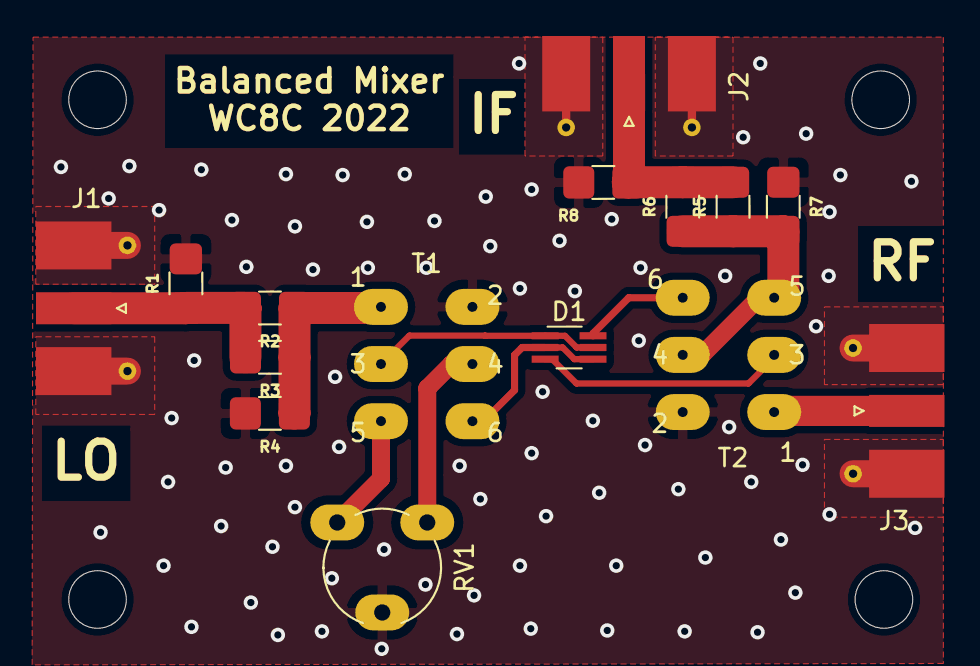
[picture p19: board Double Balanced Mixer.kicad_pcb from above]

Board: 2 copper layers, 19 parts (0 on the bottom side), 12 nets.

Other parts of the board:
 : MountingHole_3.2mm_M3
 #2,  #3,  #4: MountingHole_3.2mm_M3

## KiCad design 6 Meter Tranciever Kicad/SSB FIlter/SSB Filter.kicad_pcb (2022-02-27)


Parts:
C1, C2, C3, C4, C5, C6: 68p; SMD_Combo_1206_0805
J1, J2: Conn_Coaxial; SMA_Molex_73251-2120_EdgeMount_Horizontal
T1, T2: Impeadance Transformer; T37_AutoTransformerParallel
Y1, Y2, Y3, Y4, Y5, Y6, Y7, Y8, Y9: 12MHz; Crystal_HC49-4H_Vertical

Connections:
GNDREF: C1.2, C2.2, C3.2, C4.2, C5.2, C6.2, J1.2 (Ext), J2.2 (Ext), T1.4 (SD), T2.4 (SD)
unnamed: C1.1, Y1.2, Y2.2, Y3.1
unnamed: C2.1, Y3.2, Y4.1
unnamed: C3.1, Y4.2, Y5.1
unnamed: C4.1, Y5.2, Y6.1
unnamed: C5.1, Y6.2, Y7.1
unnamed: C6.1, Y7.2, Y8.1, Y9.1
unnamed: J1.1 (In), T1.2 (SB), T1.3 (SC)
unnamed: J2.1 (In), T2.2 (SB), T2.3 (SC)
unnamed: T1.1 (SA), Y1.1, Y2.1
unnamed: T2.1 (SA), Y8.2, Y9.2

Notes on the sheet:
Capacitors are all 1%. Determined experimentally. Each board / set of crystals may vary.
T1 and T4 startes as a 4:1 impeadance transformer 11 turns eaither side of center FT43-37. Later added 1 extra turn to ground leg to imptove impeadance match.

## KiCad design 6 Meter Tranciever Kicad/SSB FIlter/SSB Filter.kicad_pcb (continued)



Board: 2 copper layers, 76.2 x 27.9 mm, 21 parts (9 on the bottom side), 11 nets.

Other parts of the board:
 : MountingHole_3.2mm_M3
 #2: MountingHole_3.2mm_M3

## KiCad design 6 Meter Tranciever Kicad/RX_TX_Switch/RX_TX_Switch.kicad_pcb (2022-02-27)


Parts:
C1: 10u; SMD_Combo_1206_0805
C2: .1u; SMD_Combo_1206_0805
D1, D2: 1N4148; D_SOD-323_HandSoldering
D3: 6.8V; D_MiniMELF_Handsoldering
D4, D5: SM4004; D_SMA_Handsoldering
J1: Radio; SMA_Molex_73251-2120_EdgeMount_Horizontal
J2: RX from Ant; SMA_Molex_73251-2120_EdgeMount_Horizontal
J3: RX to Radio; SMA_Molex_73251-2120_EdgeMount_Horizontal
J4: TX to Ant; SMA_Molex_73251-2120_EdgeMount_Horizontal
J5: TX from Radio; SMA_Molex_73251-2120_EdgeMount_Horizontal
J6: Antenna; SMA_Molex_73251-2120_EdgeMount_Horizontal
J7: Power & RX/TX; FanPinHeader_1x03_P2.54mm_Vertical
K1: FINDER-44.52; Relay_DPDT_Omron_G5V-2
Q1: AO3400; SOT-23_Handsoldering
R1: 10K; SMD_Combo_1206_0805
R2: 3K3; SMD_Combo_1206_0805
R3: 100K; SMD_Combo_1206_0805

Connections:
/13V: D4.2 (A), J7.1
GNDREF: C1.2, C2.2, D1.1 (K), D2.2 (A), D3.2 (A), J1.2 (Ext), J2.2 (Ext), J3.2 (Ext), J4.2 (Ext), J5.2 (Ext), J6.2 (Ext), J7.3, Q1.2 (S), R1.2, R3.2
unnamed: C1.1, C2.1, D4.1 (K), D5.1 (K), K1.1, R3.1
unnamed: D1.2 (A), D2.1 (K), J2.1 (In), K1.11
unnamed: D3.1 (K), Q1.1 (G), R2.1
unnamed: D5.2 (A), K1.16, Q1.3 (D)
unnamed: J1.1 (In), K1.4
unnamed: J3.1 (In), K1.6
unnamed: J4.1 (In), K1.9
unnamed: J5.1 (In), K1.8
unnamed: J6.1 (In), K1.13
unnamed: J7.2, R1.1, R2.2


Board: 2 copper layers, 53.2 x 58.2 mm, 23 parts (0 on the bottom side), 12 nets.

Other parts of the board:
 : MountingHole_3.2mm_M3
 #2,  #3,  #4: MountingHole_3.2mm_M3

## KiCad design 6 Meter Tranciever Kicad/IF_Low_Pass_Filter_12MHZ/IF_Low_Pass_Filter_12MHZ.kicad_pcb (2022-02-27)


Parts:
C1, C3: 270p; SMD_Combo_1206_0805
C2: 470p; SMD_Combo_1206_0805
J1, J2: SMA; SMA_Molex_73251-2120_EdgeMount_Horizontal
L1, L2: 820n; C_Axial_L12.0mm_D6.5mm_P20.00mm_Horizontal

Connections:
GNDREF: C1.2, C2.2, C3.2, J1.2 (Ext), J2.2 (Ext)
unnamed: C1.1, J1.1 (In), L1.1
unnamed: C2.1, L1.2, L2.1
unnamed: C3.1, J2.1 (In), L2.2

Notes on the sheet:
Inductors are 19 turns 19mm long 24 gauge magnet wire wound tightly on a 1/4" rod (7.13 mm inner diameter after springback). Remove rod and stretch coil to 19mm. Inductor Designed at: https://m0ukd.com/calculators/air-cored-inductor-calculator/


Board: 2 copper layers, 7 parts (0 on the bottom side), 4 nets.

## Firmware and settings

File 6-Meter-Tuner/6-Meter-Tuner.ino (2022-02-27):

/*
 * Requires NewLiquidCrystal library
 * Requires TimerOne library
 * 
 * 
 * 
 */

#include "si5351mcu.h"
#include "BtnEncoder.h"
#include <LiquidCrystal_I2C.h>
#include <TimerOne.h>

// Un-Allocated Pins: 9, A2, A3

#define ENCODER_PINA               2
#define ENCODER_PINB               3
#define ENCODER_BTN                4
#define ENCODER_STEPS_PER_NOTCH    4   // Change this depending on which encoder is used

#define PTT_BTN                    5
#define CW_KEYER_PIN               A6  // CW Keyer
#define AUDIO_MUTE_PIN             6
#define TX_RX_PIN                  12
#define CW_TONE_PIN                10
#define CW_KEY                     A0  // Turns on CW carrier
#define ANALOG_SMETER              A7
#define ENGAGE_AMP_PIN             11
#define LED_PIN                    13

#define SOFT_I2C_SDA               7
#define SOFT_I2C_SCL               8

#define HARD_I2C_SDA               A4
#define HARD_I2C_SCL               A5

ClickEncoder encoder = ClickEncoder(ENCODER_PINA,ENCODER_PINB,ENCODER_BTN,ENCODER_STEPS_PER_NOTCH);
DigitalButton ptt = DigitalButton(PTT_BTN, false);

//#define LCD_I2C_ADDR     0x3F
#define LCD_I2C_ADDR     0x27
#define I2C_EN_PIN              2
#define I2C_RW_PIN              1
#define I2C_RS_PIN              0
#define I2C_D4_PIN              4
#define I2C_D5_PIN              5
#define I2C_D6_PIN              6
#define I2C_D7_PIN              7
#define I2C_BL_PIN              3   //Back light
#define I2C_BACKLIGHT_POLARITY  POSITIVE

LiquidCrystal_I2C lcd(LCD_I2C_ADDR,   // Set the LCD I2C address
                      I2C_EN_PIN,
                      I2C_RW_PIN,
                      I2C_RS_PIN,
                      I2C_D4_PIN,
                      I2C_D5_PIN,
                      I2C_D6_PIN,
                      I2C_D7_PIN,
                      I2C_BL_PIN,
                      I2C_BACKLIGHT_POLARITY);  

#define USB_FILTER                 -1
#define LSB_FILTER                 1
#define CRYSTAL_FILTER_SIDE        USB_FILTER 
#define CRYSTAL_FILTER_WIDTH       3500 
#define CRYSTAL_FILTER_UPPER_EDGE  12000600 

// Frequencies are in Hz
#define SI5351_CLOCK_FREQ  25000000
#define TUNE_START_FREQ    50000000 
#define TUNE_END_FREQ      54000000
#define BFO_BASE_FREQ      (CRYSTAL_FILTER_UPPER_EDGE - (CRYSTAL_FILTER_SIDE == 1 ? 0 : CRYSTAL_FILTER_WIDTH))
#define CW_TONE_FREQ       700
#define START_FREQ         50100000

#define VFO_CHANNEL        2
#define BFO_CHANNEL        0
#define VFO_CORRECTION     -340
#define BFO_CORRECTION     195

Si5351mcu vfoGenerator;
Si5351mcu2 bfoGenerator;

int32_t frequencyIncrement = 1000;
int32_t tuneFrequency = START_FREQ;

int32_t bfoAdjustment = 0;

void timerIsr() {
  encoder.service();
  ptt.service();
}
void setup() {
  digitalWrite(AUDIO_MUTE_PIN, HIGH);    // set to mute
  pinMode(AUDIO_MUTE_PIN, OUTPUT); // set to mute
  
  digitalWrite(LED_PIN, LOW); 
  pinMode(LED_PIN, OUTPUT);
  
  vfoGenerator.init(SI5351_CLOCK_FREQ); 
  vfoGenerator.off();
  vfoGenerator.correction(VFO_CORRECTION);
  
  bfoGenerator.init(SI5351_CLOCK_FREQ, SOFT_I2C_SDA, SOFT_I2C_SCL); 
  bfoGenerator.off();
  bfoGenerator.correction(BFO_CORRECTION);

  Serial.begin(115200);

  digitalWrite(TX_RX_PIN, LOW);
  digitalWrite(ENGAGE_AMP_PIN, LOW);
  digitalWrite(CW_KEY, LOW);
  pinMode(TX_RX_PIN, OUTPUT);
  pinMode(ENGAGE_AMP_PIN, OUTPUT);
  pinMode(CW_KEY, OUTPUT);
  pinMode(PTT_BTN, INPUT_PULLUP);
  pinMode(CW_KEYER_PIN, INPUT_PULLUP);  
  pinMode(ANALOG_SMETER, INPUT);
  
  analogWrite(CW_TONE_PIN,127);
  pinMode(CW_TONE_PIN, INPUT);  // Set to high impeadance so there is no output until we go to CW mode
  
  encoder.setDoubleClickEnabled(true);
  encoder.setButtonHeldEnabled(false);

  ptt.setDoubleClickEnabled(false);
  ptt.setButtonHeldEnabled(true);
  ptt.setHoldTime(0);

  lcd.begin(16, 2);
  lcd.clear();
  
  ajdustBFOFrequency(bfoAdjustment);
  displayRefresh(false);

  Timer1.initialize(1000);
  Timer1.attachInterrupt(timerIsr); 

  vfoGenerator.setPower(VFO_CHANNEL, SIOUT_8mA); 
  bfoGenerator.setPower(BFO_CHANNEL, SIOUT_8mA);

  vfoGenerator.enable(VFO_CHANNEL);
  bfoGenerator.enable(BFO_CHANNEL);

  delay(1000);
    digitalWrite(AUDIO_MUTE_PIN, LOW);    // un-mute

  encoder.resetEncoder();
} 

void displayRefresh(bool BfoMode){
    lcd.setCursor(0, 0);lcd.print("         ");
    lcd.setCursor(0, 0);lcd.print(tuneFrequency);
    lcd.setCursor(0, 1);lcd.print("         ");
    lcd.setCursor(0, 1);lcd.print(BFO_BASE_FREQ + bfoAdjustment);
    lcd.setCursor(9, 0);lcd.print("       ");
    lcd.setCursor(9, 1);lcd.print("       ");
    if (BfoMode) {
      lcd.setCursor(9, 1);lcd.print(frequencyIncrement);
    }
    else {
     lcd.setCursor(9, 0);lcd.print(frequencyIncrement);
     
    }
  
}

void setNewFrequency(int16_t freqChange)
{
    tuneFrequency += freqChange * frequencyIncrement;
    tuneFrequency = constrain(tuneFrequency, TUNE_START_FREQ, TUNE_END_FREQ);
    vfoGenerator.setFreq(VFO_CHANNEL, tuneFrequency + CRYSTAL_FILTER_SIDE*(BFO_BASE_FREQ + bfoAdjustment));  
}

void ajdustBFOFrequency(int16_t freqChange)
{
    bfoAdjustment += freqChange * frequencyIncrement;
    bfoAdjustment = constrain(bfoAdjustment, (BFO_BASE_FREQ) * -1 + 400000, BFO_BASE_FREQ);
    bfoGenerator.setFreq(BFO_CHANNEL, (BFO_BASE_FREQ + bfoAdjustment));
    setNewFrequency(0);  
}

void loop() {
  static bool ajdustBFO = false;

  static bool txMode = false;

  switch (ptt.getButton()) {
     case ClickEncoder::Held:
     if (!txMode) {
        Serial.println("PTT Pressed");
        digitalWrite(AUDIO_MUTE_PIN, HIGH); // mute
        delay(50);
        digitalWrite(TX_RX_PIN, HIGH);
        txMode = true;
        delay(100);
        digitalWrite(ENGAGE_AMP_PIN, HIGH);  // Pause before relay engaged because rx/tx switch can be noisy
        digitalWrite(LED_PIN, HIGH);
     }
      break;
    case ClickEncoder::Released:
      digitalWrite(ENGAGE_AMP_PIN, LOW);
      digitalWrite(LED_PIN, LOW);
      Serial.println("PTT Released");
      delay(20);                         // Pause to be sure relay has disengaged because rx/tx switch can be noisy
      digitalWrite(TX_RX_PIN, LOW);
      delay(500);
      digitalWrite(AUDIO_MUTE_PIN, LOW);    // un-mute
      txMode = false;
      break;
  }
  
  switch (encoder.getButton()) {     
    case ClickEncoder::DoubleClicked:
      Serial.println("Encoder DoubleClicked");
      ajdustBFO = !ajdustBFO;
      displayRefresh(ajdustBFO);
      break;

    case ClickEncoder::Clicked:
      Serial.println("Encoder Clicked");
      if (frequencyIncrement <= 10) {
        frequencyIncrement = 100000;
      }
      else {
        frequencyIncrement /= 10;
      }
      displayRefresh(ajdustBFO);
      break;
  }
  
  // check for frequency change
  int16_t value = encoder.getValue();  
  if (value != 0) {
    if (ajdustBFO) {
     ajdustBFOFrequency(value);
    }
    else {
     setNewFrequency(value);
    }
  displayRefresh(ajdustBFO);
  }
}

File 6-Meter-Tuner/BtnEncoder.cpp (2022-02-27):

// ----------------------------------------------------------------------------
// Rotary Encoder Driver with Acceleration
// Supports Click, DoubleClick, Long Click
//
// (c) 2010 karl@pitrich.com
// (c) 2014 karl@pitrich.com
// 
// Timer-based rotary encoder logic by Peter Dannegger
// http://www.mikrocontroller.net/articles/Drehgeber
// ----------------------------------------------------------------------------

#include "BtnEncoder.h"

// ----------------------------------------------------------------------------
// Button configuration (values for 1ms timer service calls)
//
#define ENC_BUTTONINTERVAL    10  // check button every x milliseconds, also debouce time

// ----------------------------------------------------------------------------
// Acceleration configuration (for 1000Hz calls to ::service())
//
#define ENC_ACCEL_TOP      3072   // max. acceleration: *12 (val >> 8)
#define ENC_ACCEL_INC        25
#define ENC_ACCEL_DEC         2

// ----------------------------------------------------------------------------

#if ENC_DECODER != ENC_NORMAL
#  if ENC_HALFSTEP
     // decoding table for hardware with flaky notch (half resolution)
     const int8_t ClickEncoder::table[16] __attribute__((__progmem__)) = { 
       0, 0, -1, 0, 0, 0, 0, 1, 1, 0, 0, 0, 0, -1, 0, 0 
     };    
#  else
     // decoding table for normal hardware
     const int8_t ClickEncoder::table[16] __attribute__((__progmem__)) = { 
       0, 1, -1, 0, -1, 0, 0, 1, 1, 0, 0, -1, 0, -1, 1, 0 
     };    
#  endif
#endif

// ----------------------------------------------------------------------------

ClickEncoder::ClickEncoder(int8_t A, int8_t B, int8_t BTN, uint8_t stepsPerNotch, bool active)
  : doubleClickEnabled(true),buttonHeldEnabled(true), accelerationEnabled(true),
    delta(0), last(0), acceleration(0),
    button(Open), steps(stepsPerNotch),
    pinA(A), pinB(B), pinBTN(BTN), pinsActive(active)
#ifndef WITHOUT_BUTTON
    , analogInput(false)
#endif
{
  pinMode_t configType = (pinsActive == LOW) ? INPUT_PULLUP : INPUT;
  if (pinA >= 0) {pinMode(pinA, configType);}
  if (pinB >= 0) {pinMode(pinB, configType);}
#ifndef WITHOUT_BUTTON
  if (pinBTN >= 0) {pinMode(pinBTN, configType);}
#endif
  
  if (digitalRead(pinA) == pinsActive) {
    last = 3;
  }

  if (digitalRead(pinB) == pinsActive) {
    last ^=1;
  }
}

// ----------------------------------------------------------------------------
#ifndef WITHOUT_BUTTON


// Depricated.  Use DigitalButton instead
ClickEncoder::ClickEncoder(int8_t BTN, bool active)
  : doubleClickEnabled(true),buttonHeldEnabled(true), accelerationEnabled(true),
    delta(0), last(0), acceleration(0),
    button(Open), steps(1), analogInput(false),
    pinA(-1), pinB(-1), pinBTN(BTN), pinsActive(active)
{
  pinMode_t configType = (pinsActive == LOW) ? INPUT_PULLUP : INPUT;
  if (pinBTN >= 0) {pinMode(pinBTN, configType);}
}

// ----------------------------------------------------------------------------
// Constructor for using digital input as a button

DigitalButton::DigitalButton(int8_t BTN, bool active) : ClickEncoder(BTN, active)

{

}

// ----------------------------------------------------------------------------
// Constructor for using analog input range as a button

AnalogButton::AnalogButton(int8_t BTN, int16_t rangeLow, int16_t rangeHigh) : ClickEncoder(BTN, (bool)false)
{
  pinMode(pinBTN, INPUT);
  
  anlogActiveRangeLow = rangeLow;
  anlogActiveRangeHigh = rangeHigh;
  analogInput = true;
  
  if (anlogActiveRangeLow > anlogActiveRangeHigh) {    // swap values if provided in the wrong order
    int16_t t = anlogActiveRangeLow;
    anlogActiveRangeLow = anlogActiveRangeHigh;
    anlogActiveRangeHigh = t;
  }
}
#endif

// ----------------------------------------------------------------------------
// call this every 1 millisecond via timer ISR
//
void ClickEncoder::service(void)
{
  bool moved = false;

  if (pinA >= 0 && pinB >= 0) {
    if (accelerationEnabled) { // decelerate every tick
      acceleration -= ENC_ACCEL_DEC;
      if (acceleration & 0x8000) { // handle overflow of MSB is set
        acceleration = 0;
      }
    }

#if ENC_DECODER == ENC_FLAKY
  last = (last << 2) & 0x0F;

  if (digitalRead(pinA) == pinsActive) {
    last |= 2;
  }

  if (digitalRead(pinB) == pinsActive) {
    last |= 1;
  }

  int8_t tbl = pgm_read_byte(&table[last]); 
  if (tbl) {
    delta += tbl;
    moved = true;
  }
#elif ENC_DECODER == ENC_NORMAL
  int8_t curr = 0;

  if (digitalRead(pinA) == pinsActive) {
    curr = 3;
  }

  if (digitalRead(pinB) == pinsActive) {
    curr ^= 1;
  }
  
  int8_t diff = last - curr;

  if (diff & 1) {            // bit 0 = step
    last = curr;
    delta += (diff & 2) - 1; // bit 1 = direction (+/-)
    moved = true;    
  }
#else
# error "Error: define ENC_DECODER to ENC_NORMAL or ENC_FLAKY"
#endif

  if (accelerationEnabled && moved) {
    // increment accelerator if encoder has been moved
    if (acceleration <= (ENC_ACCEL_TOP - ENC_ACCEL_INC)) {
      acceleration += ENC_ACCEL_INC;
    }
  }
}
  // handle button
  //
#ifndef WITHOUT_BUTTON
  unsigned long currentMillis = millis();
  unsigned long millisSinceLastCheck = currentMillis - lastButtonCheck;
  if ((pinBTN > 0 || (pinBTN == 0 && buttonOnPinZeroEnabled))        // check button only, if a pin has been provided
      && (millisSinceLastCheck >= ENC_BUTTONINTERVAL))            // checking button is sufficient every 10-30ms
  { 
    lastButtonCheck = currentMillis;

    bool pinRead = getPinState();

    if (pinRead == !pinsActive) { // key is now up
      if (keyDownTicks > 1) {               //Make sure key was down through 1 complete tick to prevent random transients from registering as click
        if (button == Held) {
          button = Released;
          doubleClickTicks = 0;
        }
        else {
          #define ENC_SINGLECLICKONLY 1
          if (doubleClickTicks > ENC_SINGLECLICKONLY) {   // prevent trigger in single click mode
            if (doubleClickTicks < (buttonDoubleClickTime)) {
              button = DoubleClicked;
              doubleClickTicks = 0;
            }
          }
          else {
            doubleClickTicks = (doubleClickEnabled) ? (buttonDoubleClickTime) : ENC_SINGLECLICKONLY;
          }
        }
      }

      keyDownTicks = 0;
    }
    
    if (pinRead == pinsActive) { // key is down
      if ((keyDownTicks > (buttonHoldTime)) && (buttonHeldEnabled)) {
        button = Held;
      }
      keyDownTicks += millisSinceLastCheck;
    }
  
    if (doubleClickTicks > 0) {
      doubleClickTicks -= min(millisSinceLastCheck, doubleClickTicks);
      if (doubleClickTicks == 0) {
        button = Clicked;
      }
    }
  }
#endif // WITHOUT_BUTTON

}

// ----------------------------------------------------------------------------
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

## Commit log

2022-02-27 Initial Copy
    Copying initial version
    [6 Meter Band Pass Filter.kicad_pcb, 6 Meter Band Pass Filter.sch, 6MeterPanel.stl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]
2022-03-01 Board tweaks
    Board tweaks and remove bak files
    [RF Pre Amp.kicad_pcb, RF Pre Amp.sch, TerminationInsensitiveAmplifier.kicad_pcb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]
2025-02-22 Audio Amp
    Audio Amp
    [AudioAmp.kicad_pcb, AudioAmp.kicad_sch, AudioAmp.sch]
